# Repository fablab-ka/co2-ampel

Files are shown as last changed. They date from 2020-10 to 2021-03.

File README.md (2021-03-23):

# CO2-Ampel V2
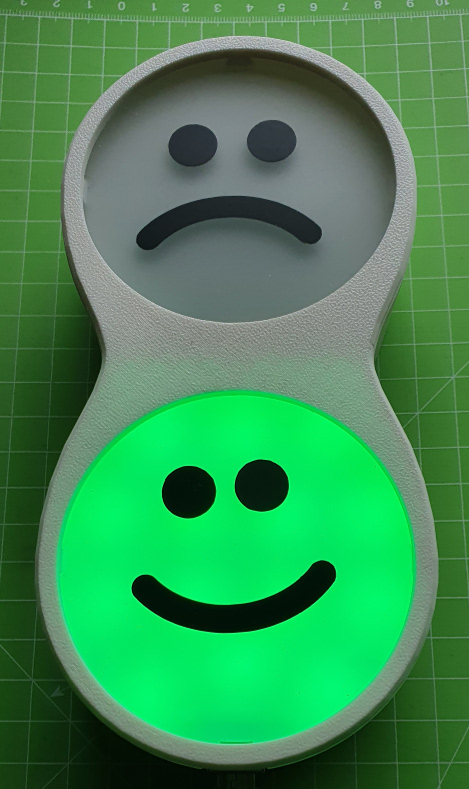
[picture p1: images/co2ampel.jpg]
CO2-Ampel


## Einleitung
Der CO2-Gehalt der Luft kann als Indikator benutzt werden, um das Raumklima zu überwachen und eine potentielle Virenlast in geschlossenen Räumen zu erkennen. In freier Natur und in frisch gelüfteten Räumen beträgt er ungefähr 400ppm (0,04%). In geschlossenen Räumen mit anwesenden Personen steigt er konstant an. Ab ca. 1500ppm wird das Raumklima schlecht, und es können Unbehaglichkeit, Müdigkeit und Konzentrationsschwächen auftreten. 

Da Viren, die als Aerosol übertragen werden, zusammen mit dem CO2 in den Raum gebracht werden, kann über den CO2-Gehalt der Raumluft als Indikator für das Ansteckungsrisiko dienen.

Mithilfe von CO2-Sensoren lässt sich der CO2-Gehalt der Raumluft überwachen. Viele vorhandenen Geräte erlauben zwar eine akkurate Messung, zeigen aber die Auswirkungen auf die Raumluft nur mit kleinen LED-Anzeigen oder überhaupt nicht an. Sie eignen sich daher nur bedingt für den Einsatz in Gruppenräumen.

## Zielsetzung
Die *CO2-Ampel V2* wurde speziell für Schulen und Kitas entwickelt. Sie zeigt das Raumklima spielerisch und gut sichtbar im Stil einer Verkehrsampel an. *Grün* bedeutet *alles in Ordnung*. Springt die Ampel auf *gelb*, wird es Zeit, die Fenster zu öffnen. Bei *rot* ist der Grenzwert überschritten. Ein akustisches Signal weist zusätzlich darauf hin, dass nunmehr umgehend gelüftet werden muss. Sobald der CO2-Gehalt sich normalisiert hat, springt die Ampel wieder auf *grün*. Ein lachender bzw. ein trauriger Smiley illustrieren das Messergebnis zusätzlich.

Das Gerät lässt sich leicht installieren und wird über ein gewöhnliches USB-Kabel mit Strom versorgt. Der eingebaute Sensor erlaubt präzise CO2-Messungen. Auf Wunsch lässt sich der Verlauf der Messwerte per WLAN in einem Web-Interface anzeigen und protokollieren.

Bei der CO2-Ampel V2 handelt es sich um ein gemeinsames Projekt des [FabLab Karlsruhe e.V.](https://fablab-karlsruhe.de) und des [FabLab Bruchsal e.V.](http://fablab-bruchsal.de) im Rahmen der Aktion [Corona-Hilfe Karlsruhe](https://coronahilfe-karlsruhe.de).

## Inbetriebnahme und Fehlerbehebung
Die [Bedienungsanleitung](Documentation/Deutsch/Bedienungsanleitung.md) der CO2-Ampel V2 erläutert alle erforderlichen Schritte zur Inbetriebnahme und zur Nutzung einer fertigen CO2-Ampel. Sie deckt die folgenden Aspekte ab:

* Installation und Stromversorgung
* Optische und akustische Signale
* Konfiguration der WLAN-Verbindung (optional)
* Zugriff auf die Messdaten und Protokolle (optional)
* Fehlerbehebung
* Technische Daten
* Entsorgung

## Aufbauanleitung (Bausatz)
Die bebilderte [Aufbauanleitung](Documentation/Deutsch/Aufbauanleitung.md) erklärt Schritt für Schritt, wie die CO2-Ampel aus den Einzelkomponenten zusammengesetzt wird. Dies umfasst die folgenden Schritte:

* Einstecken des Microcontrollers und des CO2-Sensors
* Einsetzen der Platine
* Zusammenstecken und Verschrauben des Geräts

## Beschaffung bzw. Herstellung der Komponenten
Die [Herstellungsanleitung](Documentation/Deutsch/Herstellungsanleitung.md) gibt einen Überblick, wie die Einzelkomponenten der CO2-Ampel basierend auf den Informationen in diesem GitHub-Repository hergestellt bzw. beschafft werden können. Die Anleitung umfasst die folgenden Abschnitte:

* Beschaffung der Bauteile
* Bestellung der Platine bei einem PCB-Haus
* Bestückung der Platine mit den SMD-Komponenten
* Einlöten der weiteren elektronischen Komponenten
* Kompilieren und Hochladen der Software
* Einrichtung des Webinterfaces für den Datenzugriff
* 3D-Druck des Gehäuses

In der bebilderten [Loetanleitung](Documentation/Deutsch/Loetanleitung) sind alle wichtigen Schritte zum Löten der Komponenten beschrieben. Wir haben uns hier auf das Einlöten der Through Hole Komponenten beschränkt.

## Weiterentwicklung des Projekts
Der gesamte Quellcode der CO2-Ampel V2 wurde in diesem  GitHub-Repository veröffentlicht. Er besteht aus den folgenden Komponenten:

* Platine ([Gerber](https://de.wikipedia.org/wiki/Gerber-Format))
* Software (c++)
* Gehäuse (Wahlweise [Autodesk Fusion 360](https://www.autodesk.de/products/fusion-360/overview) oder [OpenSCAD](https://www.openscad.org))

## Zusätzliche Ressourcen
  * https://wiki.fablab-karlsruhe.de/doku.php?id=projekte:2020:co2-ampel

[co2ampel]: images/co2ampel.jpg "CO2-Ampel"

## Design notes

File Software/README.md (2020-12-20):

# Arduino Sketch
## Voraussetzungen
In Klammern steht jeweils die von uns getestete Version.
- [Arduino IDE(1.8.13)][IDE]
- [Arduino core for ESP8266 WiFi chip (2.7.4)][esp8266core], siehe [Installationsanleitung von heise][esp8266heise]
- Arduino Libaries
  - [SparkFun SCD30 Arduino Library (1.0.8)][scd30lib]
  - [Adafruit BMP280 Library (2.1.0)][bmp280lib]
  - [Adafruit BME280 Library (2.1.1)][bme280lib]
  - [ArduinoJson (6.17.1)][arduinojsonlib] **HINWEIS**: Die [Version 6.17.0 hat einen Bug][arduinojsonbug] und ist daher aktuell nicht kompatibel. Bitte achtet darauf, die Version 6.17.1 oder 6.16.1 zu installieren.
  - [FastLED (3.3.3)][FstLED]
  - [PubSubClient (2.8.0)][pubsubclientlib]
  - [WiFiManager (2.0.3-alpha)][wifimanagerlib]

[IDE]: https://www.arduino.cc/en/software "aktuelle Arduino IDE(1.8.13)"
[esp8266core]: https://github.com/esp8266/Arduino "Arduino core for ESP8266 WiFi chip"
[esp8266heise]: https://www.heise.de/ct/artikel/Arduino-IDE-installieren-und-fit-machen-fuer-ESP8266-und-ESP32-4130814.html "Installationsanleitung von heise"
[scd30lib]: https://github.com/sparkfun/SparkFun_SCD30_Arduino_Library "SparkFun SCD30 Arduino Library (1.0.8)"
[bmp280lib]: https://github.com/adafruit/Adafruit_BMP280_Library "Adafruit BMP280 Library (2.1.0)"
[bme280lib]: https://github.com/adafruit/Adafruit_BME280_Library "Adafruit BMP280 Library (2.1.0)"
[arduinojsonlib]: https://github.com/bblanchon/ArduinoJson "ArduinoJson (6.16.1)"
[arduinojsonbug]: https://github.com/bblanchon/ArduinoJson/issues/1411 "Version 6.17.0 hat einen Bug"
[FstLED]: https://github.com/FastLED/FastLED "FastLED (3.3.3)"
[pubsubclientlib]: https://github.com/knolleary/pubsubclient/ "PubSubClient (2.8.0)"
[wifimanagerlib]: https://github.com/tzapu/WiFiManager "WiFiManager (2.0.3-alpha)"
[fsuploader]: https://github.com/earlephilhower/arduino-esp8266littlefs-plugin "Arduino ESP8266 LittleFS Filesystem Uploader"
## Installation
- Oben aufgeführte Libraries und Boards unter Arduino installieren
- LittleFS Uploader in <home_dir>/Arduino/tools entpacken
- Arduino Board auswählen: LOLIN(WEMOS) D1 R2 & mini

## Mikrocontroller flashen
- config.json im data Verzeichnis anpassen (MQTT Server, MQTT Zugangsdaten)
- Sketch compilieren und auf Board laden
- ESP8266 LittleFS Data Upload starten (kopiert die config.json und backup.json auf das Board). Der serielle Monitor muss dazu vorher geschlossen werden.

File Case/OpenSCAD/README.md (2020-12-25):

# OpenSCAD Case
Das Gehäuse ist nur für das PCBv2 geeignet. Das PCBv4.1 passt leider nicht. Das neuere Fusion360 v4 Gehäuse kann mit allen PCBs ab v2 verwendet werden.

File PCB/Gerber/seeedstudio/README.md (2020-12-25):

# Seedstudio PCB v2
Die Dateien beinhalten die veraltete PCB v2. Für neue Bestellungen empfehlen wir die PCB v4.1.

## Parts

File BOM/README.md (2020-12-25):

# BOM (Stückliste)

Alle Komponenten bzw. baugleiche Alternativen auch bei Digikey erhältlich. Die LEDs sind bei Digikey erheblich teurer. Der BMP280 ist nicht zwingend erforderlich, erhöht jedoch die Genauigkeit der CO2-Meßwerte.

Falls die WLAN Reichweite des D1 mini nicht ausreicht, kann alternativ der D1 mini pro mit externer Antenne eingesetzt werden. Meist muss dann der 0Ohm Widerstand auf dem D1-Board umgelötet werden. Mit den D1 mini von Aliexpress Händlern hatten wir trotz guter Bewertung teilweise sehr instabile WLAN Verbindungen.

| Nr  | MPN  | Anzahl  |Referenz |Wert|Hersteller|Footprint|LCSC-Nr|Digikey-Nr|
| --- | --- | --- | --- |--- |--- |--- |--- |--- |
|01|DMG2302UK-7|1|Q7|N-Mosfet|Diodes Incorporated|SOT-23-3|[C460977][C460977]||
|02|TCC0805X7R104M500DT|29|C2, C5-C8, C10-C33|100n| CCTC|0805_C|[C360619][C360619]||
|03|1206L110THYR|1|F1|Fuse 1A|Littelfuse|1206|[C126818][C126818] ||
|04|0805W8F4700T5E|2|R10, R12|470R|UNI-ROYAL|0805_R|[C17710][C17710]||
|05|VZH102M0JTR-0810|1|C1|1000u|Lelon|SMD,8x10mm |[C134811][C134811]||
|06|0805W8F4701T5E|3|R1, R3, R11|4.7k|UNI-ROYAL|0805_R|[C17673][C17673]|| 
|07a|BME280|1|IC1|BME280|Bosch Sensortec|LGA-8 |[C92489][C92489]||
|07b|BMP280|1|IC1|BMP280|Bosch Sensortec|LGA-8 |[C83291][C83291]||
|07c|12239814426720|1|JP1|[GY-BMP280][GY-BMP280]|AZ-Delivery|Through Hole|||
|08|SN74AHCT125DR|1|IC2|SN74AHCT125DR|Texas Instruments|SOIC-14_150mil|[C155176][C155176]||
|09|SS24|1|D1|Diode 2A| MDD(Microdiode Electronics)|SMB(DO-214AA)|[C35501][C35501]||
|10|WS2813C|28|LED1-LED28| WS2813C|Worldsemi|SMD,5x5mm |[C194323][C194323]||
|11|SK-12D02VG4|1|SW1|Switch|SOFNG SK-12D02VG4|Through Hole|[C239529][C239529]|[A107673-ND][A107673-ND]|
|12|C46392|1|J1|USB-B| Jing Extension of the Electronic Co.|Through Hole|[C46392][C46392]|[102-3999-ND][102-3999-ND]|
|13|YS-MBZ12085C05R42|1|SG1|Buzzer 5V|Fengming| 	Through Hole,12x8.5mm|[C409842][C409842]|[433-1028-ND][433-1028-ND]|
|14|SCD30|1|U$1|CO2-Sensor| Sensirion AG|Through Hole||[1649-1098-ND][1649-1098-ND]|
|15|MTF185-107SY1|1|SCD30 Header|7pin|MINTRON|Through Hole,P=2.54mm|[C358721][C358721]|[PPTC071LFBN-RC][PPTC071LFBN-RC]|
|16|28983931346|1|D1|[d1][d1] |AZDelivery|Through Hole|||
|17|[PCB-V4.1](../PCB/Gerber/jlcpcb)|1|PCB||jlcpcb||||
|18|[Case](../Case/Fusion360/Case.stl)|1|Gehäuse|PLA 0.2mm|3D-Druck||||
|19|[Lid](../Case/Fusion360/Lid.stl)|1|Deckel|PLA 0.2mm|3D-Druck||||
|20|Diffusor|2|Diffusor|[3mm Akryl opal 70% Lichtdurchlässigkeit](../Case/Laser/diffusor.svg) / [PETG transparent](../Case/Fusion360/glass_top.stl)|Lasercutter/3D-Druck||||
|21|[Smiley](../Case/SilhouetteStudio/smiley.svg)|1|Smiley|Vinyl Folie|Plotter/ausschneiden||||
|22|Netzteil|1|USB-Netzteil 5V/1A|Netzteil|diverse Hersteller||||
|23|USB-B-Kabel|1|USB-A Stekcer auf USB-B Buchse|USB-B-Kabel|diverse Hersteller||||

[C460977]: https://lcsc.com/product-detail/MOSFET_Diodes-Incorporated-DMG2302UK-7_C460977.html "C460977"
[C360619]: https://lcsc.com/product-detail/Multilayer-Ceramic-Capacitors-MLCC-SMD-SMT_CCTC-TCC0805X7R104M500DT_C360619.html "C360619"
[C126818]: https://lcsc.com/product-detail/PTC-Resettable-Fuses_Littelfuse-1206L110THYR_C126818.html "C126818"
[C17710]: https://lcsc.com/product-detail/Chip-Resistor-Surface-Mount_UNI-ROYAL-Uniroyal-Elec-0805W8F4700T5E_C17710.html "C17710"
[C134811]: https://lcsc.com/product-detail/Aluminum-Electrolytic-Capacitors-SMD_Lelon-VZH102M0JTR-0810_C134811.html "C134811"
[C17673]: https://lcsc.com/product-detail/Chip-Resistor-Surface-Mount_UNI-ROYAL-Uniroyal-Elec-0805W8F4701T5E_C17673.html "C17673"
[C92489]: https://lcsc.com/product-detail/Humidity-Sensors_Bosch-Sensortec-BME280_C92489.html "C92489"
[C83291]: https://lcsc.com/product-detail/Gas-Sensors_Bosch-Sensortec-BMP280_C83291.html "C83291"
[GY-BMP280]: https://www.az-delivery.de/en/collections/alle-produkte/products/azdelivery-bmp280-barometrischer-sensor-luftdruck-modul-fur-arduino-und-raspberry-pi "GY-BMP280"
[C155176]: https://lcsc.com/product-detail/Logic-Buffers-Drivers-Receivers-Transceivers_Texas-Instruments-SN74AHCT125DR_C155176.html "C155176"
[C35501]: https://lcsc.com/product-detail/Schottky-Barrier-Diodes-SBD_MDD-Microdiode-Electronics-SS24_C35501.html "C35501"
[C194323]: https://lcsc.com/product-detail/Light-Emitting-Diodes-LED_Worldsemi-WS2813C_C194323.html "C194323"
[C239529]: https://lcsc.com/product-detail/Lack-of-specifications_SOFNG-SK-12D02VG4_C239529.html "C239529"
[A107673-ND ]: https://www.digikey.de/product-detail/de/1825232-1/A107673-ND/4021554/?itemSeq=347804695 "A107673-ND "
[C46392]: https://lcsc.com/product-detail/USB-Connectors_Jing-Extension-of-the-Electronic-Co-C46392_C46392.html "C46392"
[102-3999-ND]: https://www.digikey.de/product-detail/de/UJ2-BH-1-TH/102-3999-ND/6187914/?itemSeq=347804690 "102-3999-ND"
[C409842]: https://lcsc.com/product-detail/Buzzers_Fengming-YS-MBZ12085C05R42_C409842.html "C409842"
[433-1028-ND]: https://www.digikey.de/product-detail/de/WT-1205/433-1028-ND/479674/?itemSeq=347804693 "433-1028-ND"
[1649-1098-ND]: https://www.digikey.de/product-detail/de/sensirion-ag/SCD30/1649-1098-ND/8445334 "1649-1098-ND"
[C358721]: https://lcsc.com/product-detail/Pin-Header-Female-Header_MINTRON-MTF185-107SY1_C358721.html "C358721"
[PPTC071LFBN-RC]: https://www.digikey.de/product-detail/de/sullins-connector-solutions/PPTC071LFBN-RC/S7005-ND/810146 "PPTC071LFBN-RC"
[d1]: https://www.az-delivery.de/products/d1-mini?variant=28983931346 "D1 Mini NodeMcu mit ESP8266-12F"

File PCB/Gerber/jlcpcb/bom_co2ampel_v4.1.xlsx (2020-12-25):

Comment | Designator | Footprint | LCSC Part #（optional）
DMG2302UK-7 | Q7 | SOT-23-3 | C460977
100n | C2, C5, C6, C7, C8, C10, C11, C12, C13, C14, C15, C16, C17, C18, C19, C20, C21, C22, C23, C24, C25, C26, C27, C28, C29, C30, C31, C32, C33 | C-EUC0805 | C49678
1206L110THYR | F1 | R-EU_R1206 | C126818
470R | R10, R12 | R-EU_R0805 | C17710
VZH102M0JTR-0810 | C1 | SMD,8x10mm | C134811
4.7k | R1, R3, R11 | R-EU_R0805 | C17673
BME280 | IC1 | LGA-8 | C92489
SN74AHCT125 | IC2 | SOIC-14_150mil | C155176
SS24 | D1 | SMB(DO-214AA) | C35501
WS2813C | LED1, LED2, LED3, LED4, LED5, LED6, LED7, LED8, LED9, LED10, LED11, LED12, LED13, LED14, LED15, LED16, LED17, LED18, LED19, LED20, LED21, LED22, LED23, LED24, LED25, LED26, LED27, LED28 | SMD,5x5mm | C194323

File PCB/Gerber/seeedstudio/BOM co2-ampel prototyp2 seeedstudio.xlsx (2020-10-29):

Designator | MPN | Qty | Link
VR1 | AZ1117EH-2.5TRG1 | 1 | https://www.digikey.de/product-detail/de/diodes-incorporated/AZ1117EH-2-5TRG1/AZ1117EH-2-5TRG1DICT-ND/5001337
Q1, Q2, Q3, Q4, Q7 | DMG2302UK-7 | 5 | https://www.digikey.de/product-detail/de/diodes-incorporated/DMG2302UK-7/DMG2302UK-7DICT-ND/6010163
C2, C5, C6, C7, C8, C9, C10, C11, C12, C13, C14, C15, C16, C17, C18, C19, C20, C21, C22, C23, C24, C25, C26, C27, C28, C29, C30, C31, C32, C33 | CC0805KRX7R9BB104 | 30 | https://www.digikey.de/product-detail/de/yageo/CC0805KRX7R9BB104/311-1140-2-ND/302874
R1, R2, R3, R4, R6, R7, R8, R9, R11 | RC0805FR-0710KL | 9 | https://www.digikey.de/product-detail/de/yageo/RC0805FR-0710KL/311-10-0KCRTR-ND/727535
C3, C4 | CC1206KKX5R8BB106 | 2 | https://www.digikey.de/product-detail/de/yageo/CC1206KKX5R8BB106/311-1466-1-ND/2833772
F1 | 0468003.NRHF | 1 | https://www.digikey.de/product-detail/de/littelfuse-inc/0468003-NRHF/F5706CT-ND/3306963
R10, R12 | RC0805JR-071KL | 2 | https://www.digikey.de/product-detail/de/yageo/RC0805JR-071KL/311-1-0KARCT-ND/731165
C1 | HV102M6R3F105ETR | 1
IC2 | BMP280 | 1 | https://www.digikey.de/product-detail/de/bosch-sensortec/BMP280/828-1064-1-ND/6136315
D1 | SS24T3G | 1 | https://www.digikey.de/product-detail/de/on-semiconductor/SS24T3G/SS24T3GOSCT-ND/964638
LED1, LED2, LED3, LED4, LED5, LED6, LED7, LED8, LED9, LED10, LED11, LED12, LED13, LED14, LED15, LED16, LED17, LED18, LED19, LED20, LED21, LED22, LED23, LED24, LED25, LED26, LED27, LED28 | WS2813C | 28

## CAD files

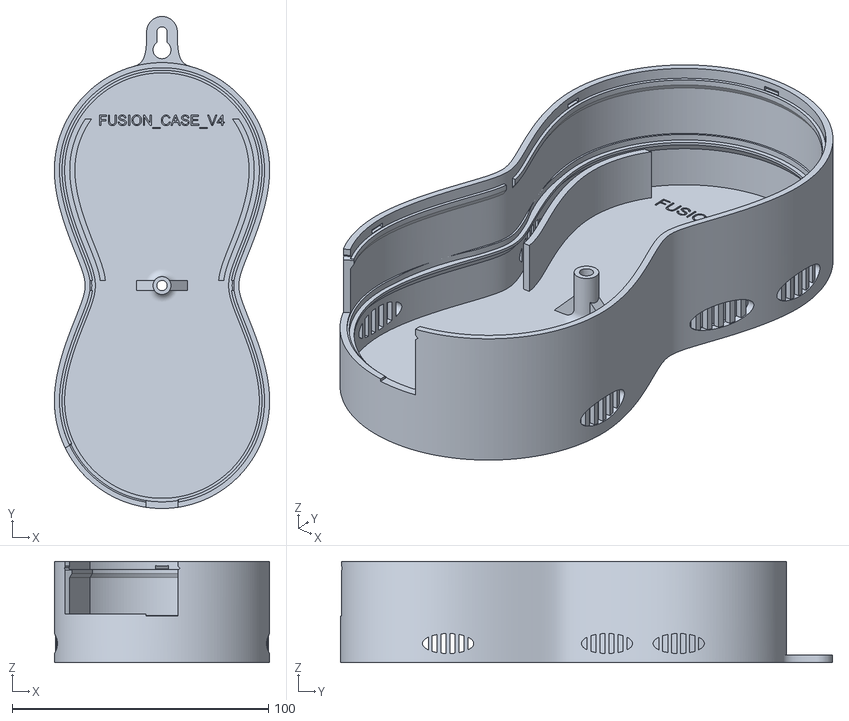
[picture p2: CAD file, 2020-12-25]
Case/Fusion360/Case.stl
84.0 x 192.0 x 39.6

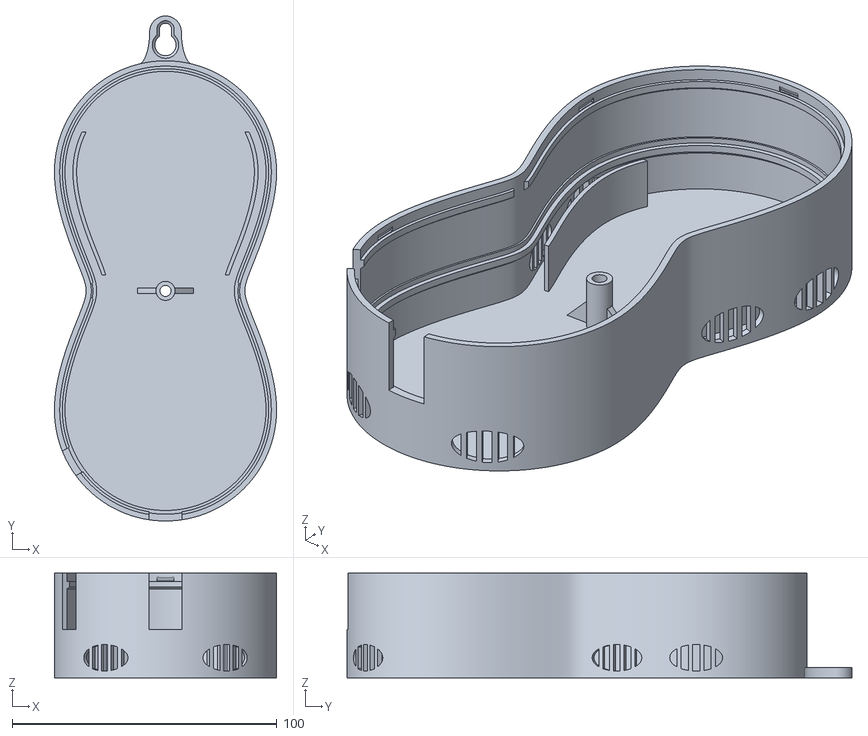
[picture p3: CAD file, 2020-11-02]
Case/OpenSCAD/PCBv2/case.stl
84.0 x 190.9 x 39.6

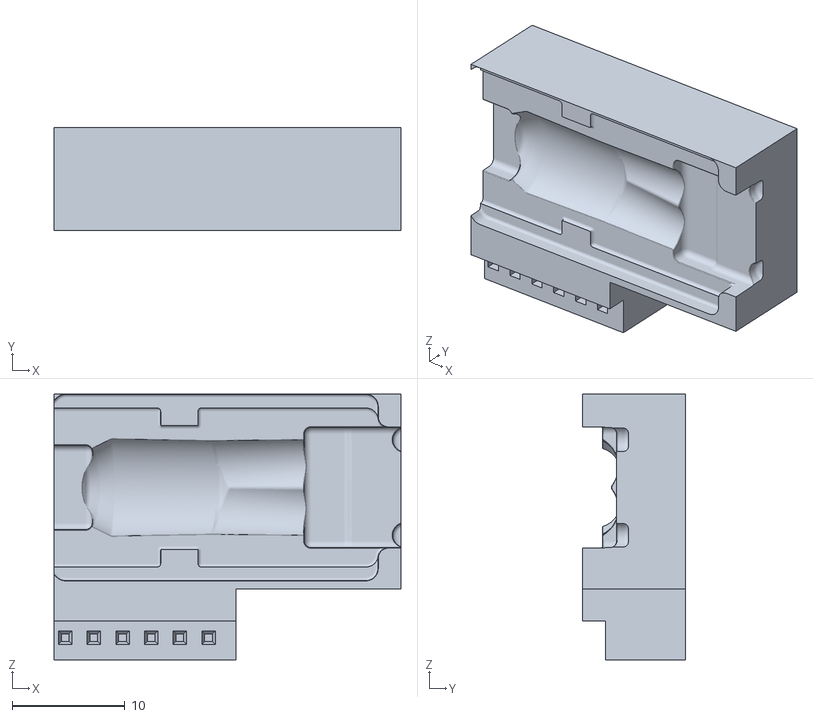
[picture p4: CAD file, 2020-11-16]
PCB/scd30-bestuecken.stl
30.7 x 9.08 x 23.5

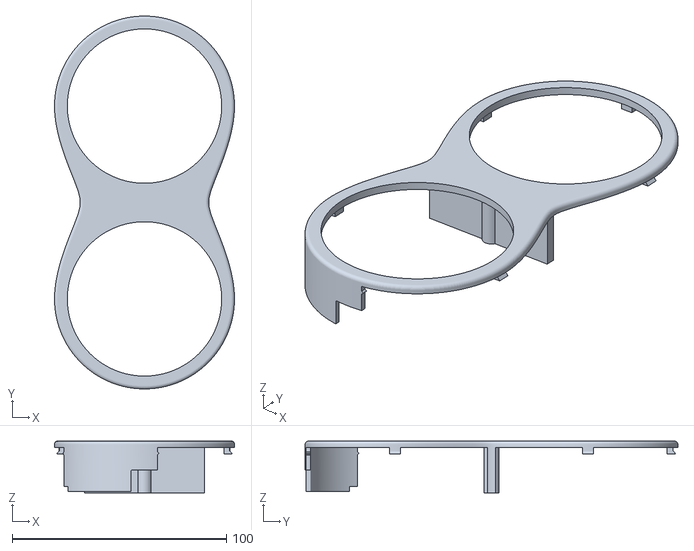
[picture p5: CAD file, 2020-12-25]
Case/Fusion360/Lid.stl
84.0 x 174.0 x 24.2

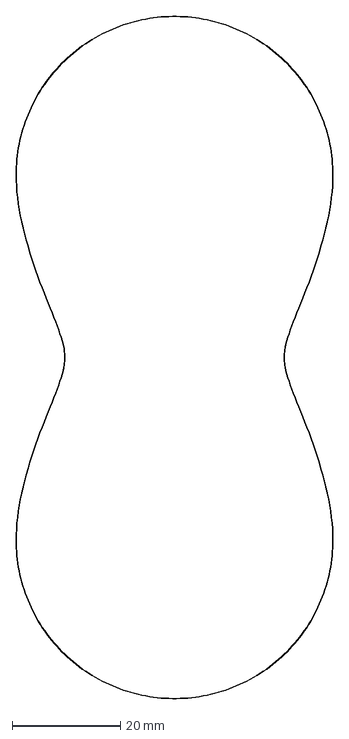
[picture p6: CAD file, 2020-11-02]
Case/OpenSCAD/PCBv2/pcb_v2.dxf
58.5 x 126.0 mm

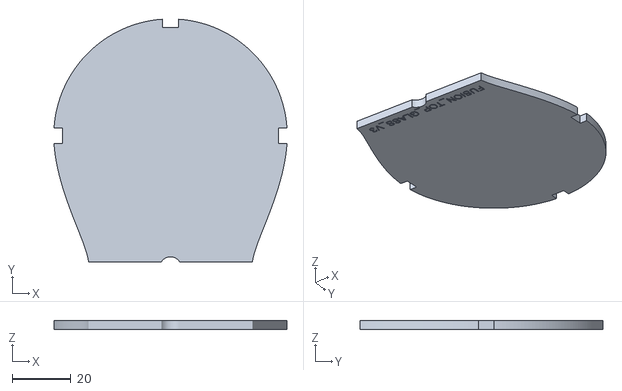
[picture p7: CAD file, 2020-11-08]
Case/Fusion360/glass_top.stl
79.4 x 82.7 x 3.00

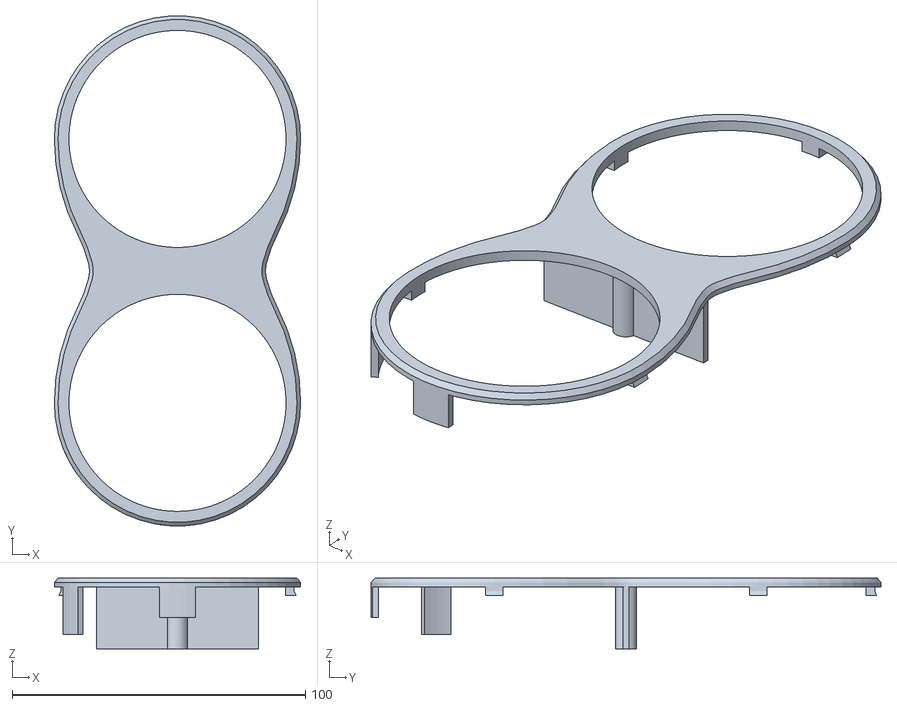
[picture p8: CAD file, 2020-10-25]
Case/OpenSCAD/PCBv2/lid.stl
84.0 x 173.9 x 24.2

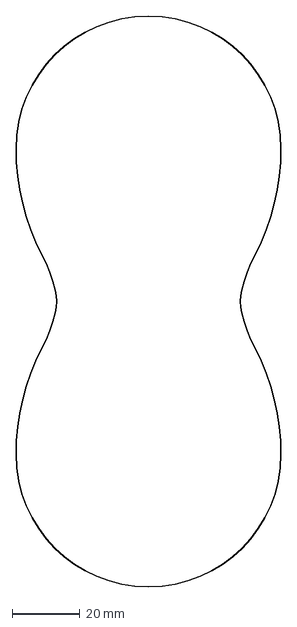
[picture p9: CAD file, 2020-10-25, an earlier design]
Case/OpenSCAD/PCBv2/pcb.dxf
78.0 x 168.0 mm

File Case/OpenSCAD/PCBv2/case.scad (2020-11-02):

use </mnt/io/gemeinsam/prusa/Bevel_Extrude_Module_for_OpenSCAD/bevel_extrude.scad>

$fn=100;
pcb_length=168;
pcb_width=78;


wall=2; //min=2 !
base=1.6;
gap=1;

enclosure();

module enclosure(){
    difference(){
        union(){
            difference(){
                union(){
                    translate([-39,-84,0]) linear_extrude(height=base+38, center = false, convexity = 200) offset(r=wall+gap) import (file = "pcb_v2.dxf");
                    translate([0,88.9+wall,2]) wallFastening();
                }
                translate([-39,-84,0]) translate([0,0,base]) linear_extrude(height=38, center = false, convexity = 200) offset(r=gap)  import (file = "pcb_v2.dxf");
                //translate([0,0,0.5*base]) cylinder(d1 = 10.2, d2 = 4.2, h = base, center = true);
                //translate([0,0,1]) cylinder(d1 = 10.2, d2 = 4.2, h = 2, center = true);
                translate([0,0,0.5*base]) cylinder(d1 = 10.8, d2 = 4.2, h = base, center = true);
        
                airConditioning();
                //antennaHole();
            }
            screwFastening();
            pcbBearing();
            difference(){
                lidBearing();
                translate([25,0,base+33]) cylinder(d = 8, h = 5, center = true);
                translate([-25,0,base+33]) cylinder(d = 8, h = 5, center = true);
            }
            blowProtection();
        }
        powerHole();
        switchHole();
        lidFastening();
    }
}


module pcb(){
color("green")  linear_extrude(height = 1.6, center = false, convexity = 200)
   import (file = "pcb_v2.dxf");       
}


module antennaHole(){
    r = 39.8;
    alpha = 120;

    translate([0,45,base+6]) translate([r*cos(alpha),r*sin(alpha),0]) rotate([0,0,alpha])
    rotate([0,90,0]) cylinder(d=6.4, h=10, center = true);
}


module lidFastening(){
    r = 39.8;
    
    //top segment
    translate([0,45,base+35]){
        alpha = 90;
        translate([r*cos(alpha),r*sin(alpha),0]) rotate([0,0,alpha]) lidHole();
    
        beta = 0;
        translate([r*cos(beta),r*sin(beta),0]) rotate([0,0,beta]) lidHole();
    
        gamma = 180;
        translate([r*cos(gamma),r*sin(gamma),0]) rotate([0,0,gamma]) lidHole();
    }
    
    //base segment
    translate([0,-45,base+35]){
        beta = 0;
        translate([r*cos(beta),r*sin(beta),0]) rotate([0,0,beta]) lidHole();
    
        gamma = 180;
        translate([r*cos(gamma),r*sin(gamma),0]) rotate([0,0,gamma]) lidHole();
    }
}


module lidHole(){
    rotate([90,0,0]) linear_extrude(height = 6.5, center = true) polygon(points = [[0,0], [0.8,0], [0,1.6]]);
}


module wallFastening(){
    difference(){
        union(){
            cube([21,14,4], center = true);
            translate([0,7,0]) cylinder(d=12, h=4, center = true);
        }
        translate([10.5,7,0]) scale([1,2.75,1]) cylinder(d=9, h=4, center =true);
        translate([-10.5,7,0]) scale([1,2.75,1]) cylinder(d=9, h=4, center =true);
        translate([0,2,0]) cylinder(d = 8, h = 4, center = true);
        translate([0,8,0]) cylinder(d = 4.5, h = 4, center = true);
        translate([0,4,0]) cube([4.5,8,4], center = true); 
        
        translate([0,0,4]) mirror([0,0,1]) bevel_extrude(height=4, bevel_depth=2, $fn=50)
        union(){
            translate([0,2,0]) circle(d=10);
            translate([0,4,0]) square([6.5, 8], center = true);
            translate([0,8,0]) circle(d=6.5);
        }
    }
}


module switchHole(){
    alpha = -151;
    translate([45*cos(alpha),45*sin(alpha)-45,base+28.6]) rotate([0,0,alpha]) cube([15,10.6,24], center = true);
}


module powerHole(){
    translate([0,-85,base+28.6]) cube([12.4,10,24], center = true);
}


module airConditioning(){
    //top segment
    translate([42,45,base+6]) airHole(4);    //right side
    translate([35,15,base+6]) rotate([0,0,-20]) airHole(4);  //right side

    translate([-42,45,base+6]) airHole(4);   //left side
    translate([-35,15,base+6]) rotate([0,0,20]) airHole(4);  //left side
    
    //translate([42,45,base+24]) airHole(4);    //right side
    //translate([-42,45,base+24]) airHole(4);   //left side
    
    //base segment
    alpha = 30; //bottom = -90°
    translate([45*cos(-90+alpha),45*sin(-90+alpha)-40,base+6]) rotate([0,0,-90+alpha]) airHole(4);
    translate([45*cos(-90-alpha),45*sin(-90-alpha)-40,base+6]) rotate([0,0,-90-alpha]) airHole(4);
    
    //translate([45*cos(-90+alpha),45*sin(-90+alpha)-40,base+24]) rotate([0,0,-90+alpha]) airHole(4);
    //translate([45*cos(-90-alpha),45*sin(-90-alpha)-40,base+24]) rotate([0,0,-90-alpha]) airHole(4);
}


module airHole(n){
    l=20;
    d=1.6;
    a = (l-n*d)/(n+1);
    difference(){
        scale([1,2,1]) rotate([0,90,0]) cylinder(d = 0.5*l, h = 10, center = true);
        for (i = [0:1:n]){
            translate([0,((0.5+i)*d+(i+1)*a)-10,0]) cube([15,d,15], center = true);
        }
    }
}


module blowProtection(){
    difference(){
         translate([-39,-84,base]) linear_extrude(height = 14.5, center = false, convexity = 200) offset(r=-4)  import (file = "pcb_v2.dxf");
        translate([-39,-84,base]) linear_extrude(height = 14.5, center = false, convexity = 200) offset(r=-5.4)  import (file = "pcb_v2.dxf");
        translate([0,-44,base+7.25]) cube([100,100,14.5], center = true);
        translate([0,85,base+7.25]) cube([100,50,14.5], center = true);
    }
}


module lidBearing(){
    translate([-39,-84,0]) translate([0,0,base+34.8]) mirror([0,0,1]) bevel_extrude(height=10, bevel_depth=8, $fn=50) lidBearingSkew();
    
}


module lidBearingSkew(){
    difference(){
        offset(r=gap+1.6)  import (file = "pcb_v2.dxf");
        offset(r=gap-1)  import (file = "pcb_v2.dxf");
    }
}


module pcbBearing(){
    difference(){
        translate([-39,-84,0]) translate([0,0,base+15]) linear_extrude(height = 1.6, center = false, convexity = 200) offset(r=gap)  import (file = "pcb_v2.dxf");
        //translate([-39,-84,0]) translate([0,0,base+15]) linear_extrude(height = 1.6, center = false, convexity = 200) offset(r=gap-0.8)  import (file = "pcb_v2.dxf");
        translate([-39,-84,0]) translate([0,0,base+15]) linear_extrude(height = 1.6, center = false, convexity = 200) offset(r=gap-0.6)  import (file = "pcb_v2.dxf");
    }

    translate([-39,-84,0]) translate([0,0,base+15]) mirror([0,0,1]) bevel_extrude(height=10, bevel_depth=8, $fn=50) pcbBearingSkew();
}


module pcbBearingSkew(){
    difference(){
        offset(r=gap+1.6) import (file = "pcb_v2.dxf");
        offset(r=gap-2) import (file = "pcb_v2.dxf");
    }
}


module screwFastening(){
    translate([0,0,base]){
        difference(){
            union(){
                cylinder(d = 7.2, h = 15);
                rotate([0,45,0]) cube([15,2,15], center = true);
            }
            translate([0,0,-6]) cube([20,4,12], center = true);
            translate([0,0,-base]) cylinder(d = 4.2, h = base + 18.1);
        }
    }
}

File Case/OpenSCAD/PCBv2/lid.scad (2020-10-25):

// CO2 Ampel - Case
// By: FabLab Karlsruhe e.V., Martina Feger
// Date: 19.10.2020
// License: MIT

// https://www.thingiverse.com/thing:135408/files
use <Bevel_Extrude_Module_for_OpenSCAD/bevel_extrude.scad>

$fn=100;
pcb_length=168;
pcb_width=78;

wall=2; //min=2 !
base=2;
lidThick=3;
gap=1;  //puffer (auf jeder seite) zwischen pcb und gehaeuse

lid();

module lid(){
    difference(){
        union(){
            mirror([0,0,1]) translate([-39,-84,lidThick]) mirror([0,0,1]) bevel_extrude(height=lidThick, bevel_depth=(0.5*lidThick), $fn=50) offset(r=wall+gap) import (file = "/mnt/io/gemeinsam/co2ampel/pcb.dxf");
            screwFastening();
            lidFastening();
        }
        translate([0,45,-10]) cylinder(d=74, h=20, center = false); //top window
        translate([0,-45,-10]) cylinder(d=74, h=20, center = false); //bottom window
    }
    powerHoleFilling();
    switchHoleFilling();
}


module lidFastening(){
    lidHoleFilling(0,"top");
    lidHoleFilling(90,"top");
    lidHoleFilling(180,"top");
    
    lidHoleFilling(0,"bottom");
    lidHoleFilling(180,"bottom");
}


module lidHoleFilling(alpha, segment){
    r = 39.8;
    if (segment == "top"){
        intersection(){
            translate([-39,-84,-(8+lidThick)]) linear_extrude(height=8, center = false, convexity = 200) offset(r=1) import (file = "/mnt/io/gemeinsam/co2ampel/pcb.dxf");
            translate([0,45,-(lidThick+1.5)]) translate([r*cos(alpha),r*sin(alpha),0]) rotate([0,0,alpha]) translate([-4,0,0]) cube([8,6,3], center = true);
        }
        translate([0,45,-(lidThick+3)]) translate([r*cos(alpha),r*sin(alpha),0]) rotate([0,0,alpha]) rotate([90,0,0]) linear_extrude(height = 6, center = true) polygon(points = [[0,0], [0.7,0], [0,1.5]]);
    } else if (segment == "bottom"){
        intersection(){
            translate([-39,-84,-(8+lidThick)]) linear_extrude(height=8, center = false, convexity = 200) offset(r=1) import (file = "/mnt/io/gemeinsam/co2ampel/pcb.dxf");
            translate([0,-45,-(lidThick+1.5)]) translate([r*cos(alpha),r*sin(alpha),0]) rotate([0,0,alpha]) translate([-4,0,0]) cube([8,6,3], center = true);
        }
        translate([0,-45,-(lidThick+3)]) translate([r*cos(alpha),r*sin(alpha),0]) rotate([0,0,alpha]) rotate([90,0,0]) linear_extrude(height = 6, center = true) polygon(points = [[0,0], [0.7,0], [0,1.5]]);
    }
}



module powerHoleFilling(){
    translate([0,0,-10.4]) intersection(){
        difference(){
            translate([-39,-84,-lidThick]) linear_extrude(height=10.4, center = false, convexity = 200) offset(r=wall+gap) import (file = "/mnt/io/gemeinsam/co2ampel/pcb.dxf");
            translate([-39,-84,-lidThick]) linear_extrude(height=10.4, center = false, convexity = 200) offset(r=gap)  import (file = "/mnt/io/gemeinsam/co2ampel/pcb.dxf");
        }
        //translate([0,-85,0]) cube([12.4,10,24], center = true);
        translate([0,-85,0]) cube([12.2,10,24], center = true);
    }
}


module switchHoleFilling(){
    translate([0,0,-16.2]) intersection(){
        difference(){
            translate([-39,-84,-lidThick]) linear_extrude(height=16.2, center = false, convexity = 200) offset(r=wall+gap) import (file = "/mnt/io/gemeinsam/co2ampel/pcb.dxf");
            translate([-39,-84,-lidThick]) linear_extrude(height=16.2, center = false, convexity = 200) offset(r=gap)  import (file = "/mnt/io/gemeinsam/co2ampel/pcb.dxf");
        }
        alpha = -151;
        //translate([45*cos(alpha),45*sin(alpha)-45,13]) rotate([0,0,alpha]) cube([15,10.6,34], center = true);
        translate([45*cos(alpha),45*sin(alpha)-45,13]) rotate([0,0,alpha]) cube([15,10.4,34], center = true);
    }
}


module screwFastening(){
    translate([0,0,-(21.2+lidThick)]){
        difference(){
            union(){
                cylinder(d = 7.2, h = 21.2, centre = true);
                translate([0,0,10.6]) cube([55.4,2,21.2], center = true);
            }
            cylinder(d = 3.2, h = 21.2, center = true);
        }
    }
}

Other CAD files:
Case/Fusion360/glass_bottom.stl

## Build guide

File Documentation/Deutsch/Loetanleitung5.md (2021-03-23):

# CO2-Ampel Lötanleitung - PCB v4.1

## Teil V - Platine prüfen
### Benötigte Bauteile
1. Platine aus Schritt IV

### Benötigtes Werkzeug
* Multimeter

In diesem Teil messen wir mit einem Multimeter, ob es eine Kurzschluss zwischen plus und minus bzw. zwischen den Datenleitungen vorhanden ist. Die könnten beim ersten Einschalten dazu führen, dass die Bauteile oder die Platine beschädigt wird.

### Arbeitsschritte
1. Stellt eurer Multimeter entweder auf Durchgangsprüfer oder auf den niedrigsten Widerstandswert ein. Wenn ihr jetzt testweise die Messspitzen aneinander haltet, piept es entweder, oder es wird ein sehr kleiner Widerstand (ca. 0.1 Ohm) angezeigt.
2. An der BMP280 Platine sind fast alle zu messenden Leitungen vorhanden. Haltet die Messspitzen als erstes an VCC und GND. Wenn das Multimeter piepst oder einen kleinen Widerstand anzeigt, habt ihr einen Kurzschluss und müsst nochmals alle Lötstellen prüfen. Wiederholt die Messung mit folgenden Pins:
  * 3V3 + SCL
  * 3V3 + SDA
  * GND + SCL
  * GND + SDA
  * SCL + SDA

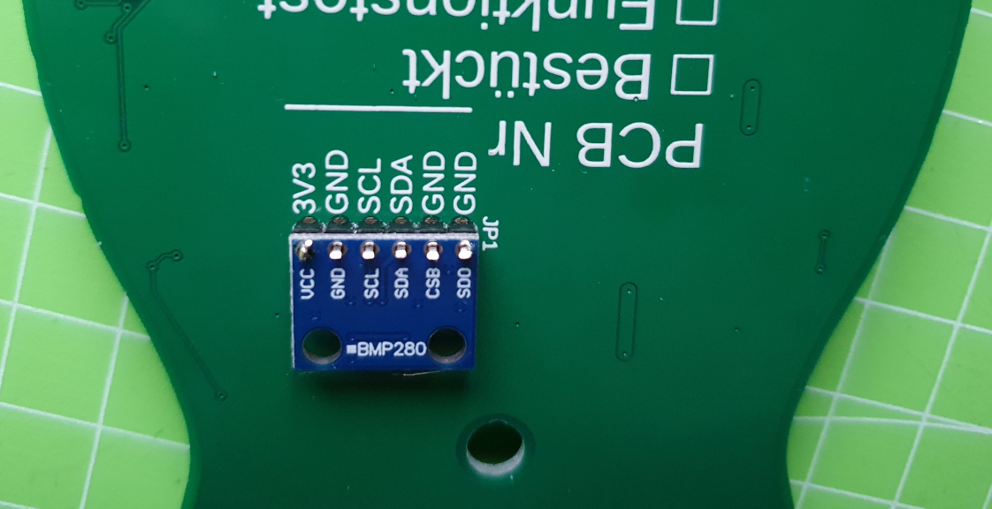
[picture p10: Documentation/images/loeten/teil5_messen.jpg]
Bauteile und Werkzeug Teil V


3. Als letztes messen wir noch den Widerstand zwischen 5V und Masse (GND). Das geht am besten an den beiden linken unteren PINs des Mikrocontrollers (siehe Bild) 

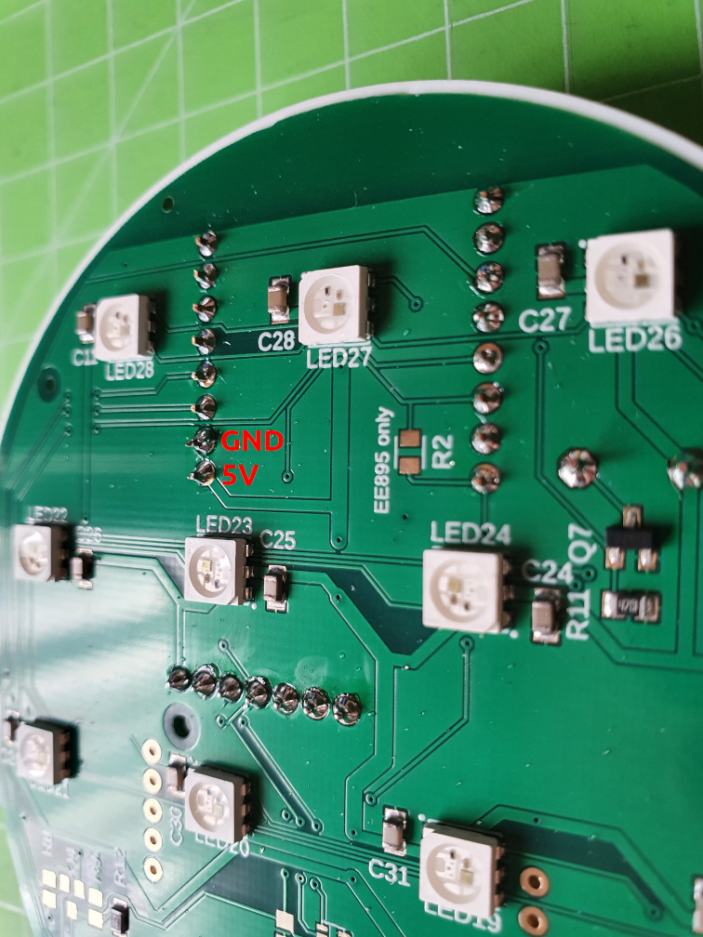
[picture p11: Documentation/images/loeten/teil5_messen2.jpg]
Bauteile und Werkzeug Teil V


**Die Ampel darf erst an den Strom angeschlossen werden, wenn alle Kurzschlüsse beseitigt sind**

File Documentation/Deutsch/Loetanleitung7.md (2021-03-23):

# CO2-Ampel Lötanleitung - PCB v4.1

## Teil VII - Test der Ampel

### Benötigte Bauteile
1. geprüfte Platine aus Schritt VI
2. USB-Netzteil
3. USB-Kabel (A-Stecker auf B-Stecker)

Bauteile und Werkzeug Teil VII

### Arbeitsschritte
1. Schutzaufkleber auf dem Buzzer entfernen
2. CO2-Ampel mit dem Kabel an das Netzteil anschließen
3. Selbsttest abwarten. Wenn alles richtig gemacht wurde, leuchten zuerst alle LEDs kurz weiß und blinken dann grün. 
4. CO2-Sensor leicht anpusten. Er sollte nach ein paar Sekunden auf gelb/rot springen und der Buzzer sollte zu hören sein. 
5. Wenn der Selbsttest erfolgreich war und auch der Buzzer funktioniert, könnt ihr die Ampel [fertig zusammen bauen](Aufbauanleitung.md) und dann direkt einsetzen.

Wir hoffen es hat alles geklappt und ihr hattet Spaß beim Löten. Wenn es Probleme gibt oder ihr unsicher seid, dann meldet euch gerne bei uns.

### Eure FabLabs Karlsruhe & Bruchsal

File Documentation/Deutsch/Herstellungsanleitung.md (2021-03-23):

# Herstellungsanleitung CO2-Ampel V2

> Hinweis: Dieses Dokument ist in Arbeit

## Benötigtes Werkzeug

* 3D Drucker
* Lötkolben
* optional: Reflow Ofen (falls das PCB selbst bestückt werden soll)
* optional: Lasercutter (falls der Diffusor aus Acryl gelasert statt gedruckt werden soll)
* optional: Plotter für die Vinyl-Folie (Augen, Mund)

## Komponenten

* 1 Gehäuse mit Deckel
* 2 Scheiben
* Aufkleber für die beiden Smileys
* Platine mit bereits eingelöteten SMD-Komponenten
* CO2-Sensor
* 1 Buchsenleiste, Polzahl 7 
* 1 Stiftleiste, Polzahl 7
* Lötleisten für CO2-Sensor (Länge 7)
* 1 ESP8266 (WeMos D1 mini V2)
* 2 Buchsenleisten, Polzahl 8 
* 2 Stiftleisten, Polzahl 8
* Schalter
* USB-Buchse
* Schraube
* Typenschild

## Einlöten der elektronischen Komponenten

* Setzt eine gewisse Erfahrung im Umgang mit Lötapparaten voraus
* Nur Elektronik-Lötapparat mit feiner Spitze
* Bleifreies Lötzinn empfohlen

In der bebilderten [Loetanleitung](Documentation/Deutsch/Loetanleitung) sind alle wichtigen Schritte zum Löten der Komponenten beschrieben. Wir haben uns hier auf das Einlöten der Through Hole Komponenten beschränkt.

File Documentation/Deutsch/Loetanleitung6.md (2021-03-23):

# CO2-Ampel Lötanleitung - PCB v4.1

## Teil VI - CO2-Sensor

### Benötigte Bauteile
1. geprüfte Platine aus Schritt V
2. Stiftleiste 7pin
3. scd30 CO2-Sensor

### Benötigtes Werkzeug
* 3D-gedruckte Löthilfe für den scd30
* Lötstation (temperaturgeregelt)
* Lötrauchabsaugung
* Lötzinn (bleifrei 0.5-0.75mm Durchmesser)
* Erdungsarmband

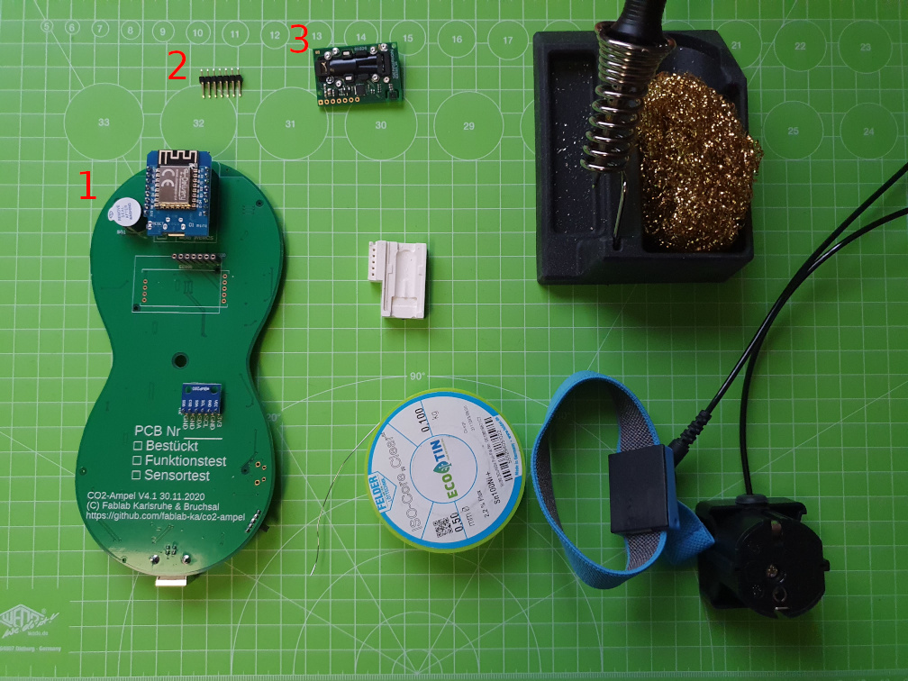
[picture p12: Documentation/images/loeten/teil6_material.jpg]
Bauteile und Werkzeug Teil VI


### Arbeitsschritte
Der Sensor ist das teuerste Bauteil und sehr empfindlich. Wenn ihr hier zu lange an einer Stelle lötet oder mit der heißen Lötspitze eines der SMD-Bauteile auf der Platine  berührt, könnt ihr ihn irreparabel beschädigen.

Der Sensor ist außerdem empfindlich gegen elektrostatische Aufladung. Ihr solltet daher bei diesem Schritt ein **Erdungsarmband tragen** und ihn nur am Rand anfassen.

1. Stiftleiste in die Löthilfe stecken (kurze Beine schauen raus)

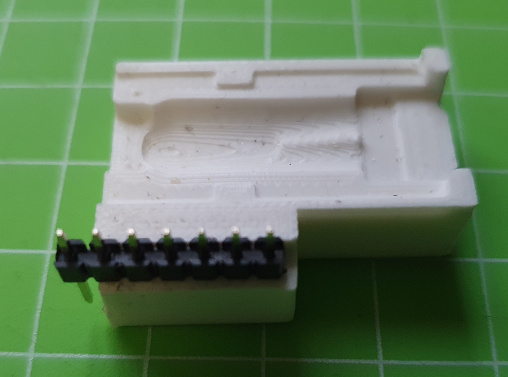
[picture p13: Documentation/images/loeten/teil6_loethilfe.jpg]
scd30 loethilfe 1


2. Sensor einlegen (es gibt nur eine Position die passt). Vorsichtig andrücken.

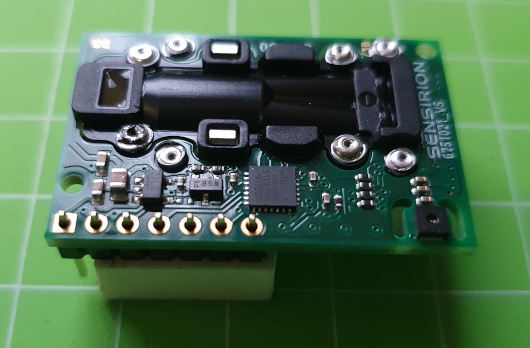
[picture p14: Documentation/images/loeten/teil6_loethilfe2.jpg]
scd30 loethilfe 2


3. Pins vorsichtig löten
4. **Qualitätskontrolle:** Auch nach diesem Schritt bitte nochmal alle Lötstellen wie oben beschrieben prüfen. 
5. Sensor auf die Platine stecken. Hier müsst ihr unbedingt darauf achten, dass der Sensor richtig sitzt und alle Pins in der Buchse stecken. **Wenn ihr ihn nur um einen Pin versetzt einsteckt, wird er beim Einschalten sofort zerstört.**

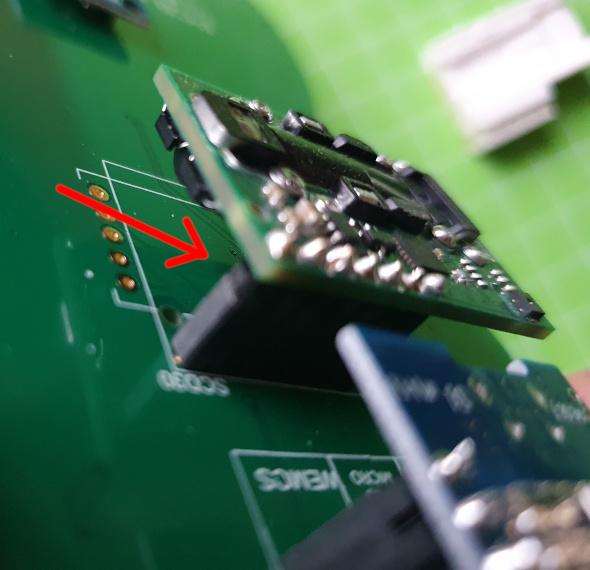
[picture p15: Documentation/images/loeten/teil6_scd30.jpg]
scd30 richtig auf die Platine stecken


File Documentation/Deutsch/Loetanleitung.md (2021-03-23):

# CO2-Ampel Lötanleitung - PCB v4.1

## Vorbereitung
Den D1 Mikrocontroller könnt ihr schon vorab mit dem Arduino Programm flashen. Dann könnt ihr direkt nach dem Löten die Ampel testen.

Prüft bitte bevor ihr beginnt, ob ihr alle benötigten Teile und Werkzeuge habt:

## Benötige Bauteile
* Buchse 8pin (2x): Diese findet ihr beim D1 Mikrocontroller
* Buchse 7pin (1x)
* bmp280 Platine
* Stiftleiste 6pin (1x): Diese findet ihr bei der bmp280 Platine
* Stiftleiste 8pin (2x): Diese findet ihr beim D1 Mikrocontroller
* D1 Mikrocontroller
* Buzzer (1x)
* SMD bestückte Platine
* USB-Buchse
* Schalter
* scd30 CO2-Sensor
* Stiftleiste 7pin
* USB-Netzteil
* USB-Kabel (A-Stecker auf B-Stecker)

## Benötigtes Werkzeug
* 3D-gedruckte Löthilfe für die Platine
* 3D-gedruckte Löthilfe für den scd30
* Lötstation (temperaturgeregelt)
* Lötrauchabsaugung
* Lötzinn (bleifrei 0.5-0.75mm Durchmesser)
* Seitenscheider
* Schutzbrille
* Multimeter
* Erdungsarmband
* evtl. eine Entlötpumpe, falls doch mal ein Bauteil falsch eingelötet wurde

Die Lötanleitung besteht aus 7 Teilen (inkl. Test der Ampel):

* [Teil I: Stiftleisten, Sockel und Buzzer](Loetanleitung1.md)
* [Teil II: USB-Buchse und Schalter](Loetanleitung2.md)
* [Teil III: bmp280 Zusatzplatine](Loetanleitung3.md)
* [Teil IV: D1 Mikrocontroller](Loetanleitung4.md)
* [Teil V - Platine prüfen](Loetanleitung5.md)
* [Teil VI - CO2-Sensor](Loetanleitung6.md)
* [Teil VII - Test der Ampel](Loetanleitung7.md)

Wir wünschen euch viel Spaß beim Löten.
Eure FabLabs Karlsruhe & Bruchsal

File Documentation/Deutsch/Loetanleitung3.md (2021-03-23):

# CO2-Ampel Lötanleitung - PCB v4.1

## Teil III: bmp280 Zusatzplatine

### Benötigte Bauteile
1. Platine aus Teil II
2. bmp280 Platine

### Benötigtes Werkzeug
* 3D-gedruckte Löthilfe für die Platine
* Lötstation (temperaturgeregelt)
* Lötrauchabsaugung
* Lötzinn (bleifrei 0.5-0.75mm Durchmesser)
* Seitenschneider

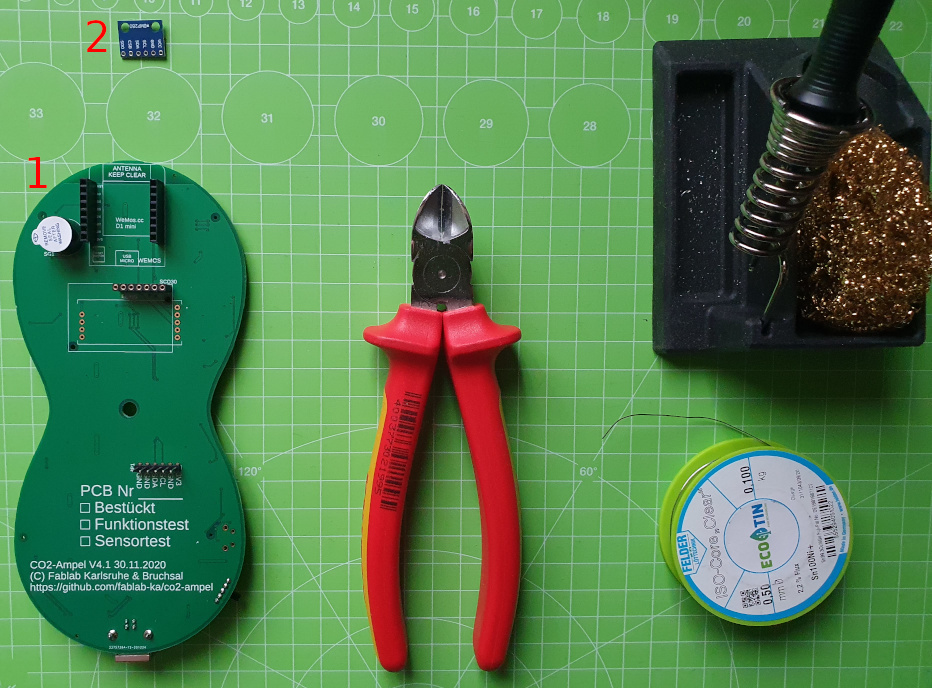
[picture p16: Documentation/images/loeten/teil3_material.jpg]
Bauteile und Werkzeug Teil III


### Arbeitsschritte
1. Legt die kleine Platine so wie auf dem Bild zu sehen, auf die Stiftleiste. **WICHTIG:** Prüft hier nochmals, ob sie richtig herum platziert wurde (**3.3V = VCC**).

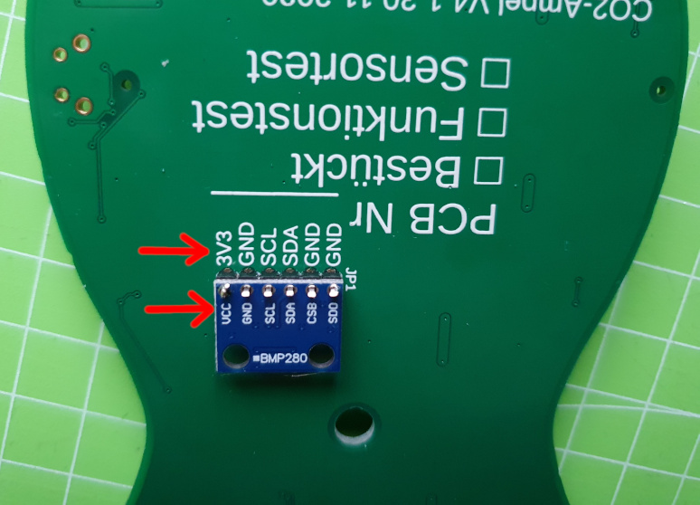
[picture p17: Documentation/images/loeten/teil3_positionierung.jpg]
bmp280 Positionierung


2. Haltet die kleine Platine waagerecht und lötet den ersten Pin. Wenn das Lötzinn kalt ist, könnt ihr die Platine los lassen und nochmal prüfen, ob sie waagerecht sitzt.
3. Lötet die restlichen Pins
4. **Qualitätskontrolle:** Auch nach diesem Schritt bitte nochmal alle Lötstellen wie oben beschrieben prüfen.

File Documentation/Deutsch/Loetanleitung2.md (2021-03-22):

# CO2-Ampel Lötanleitung - PCB v4.1

## Teil II: USB-Buchse und Schalter

### Benötigte Bauteile
1. Platine aus Teil I
2. USB-Buchse
3. Schalter

### Benötigtes Werkzeug
* 3D-gedruckte Löthilfe für die Platine
* Lötstation (temperaturgeregelt)
* Lötrauchabsaugung
* Lötzinn (bleifrei 0.5-0.75mm Durchmesser)

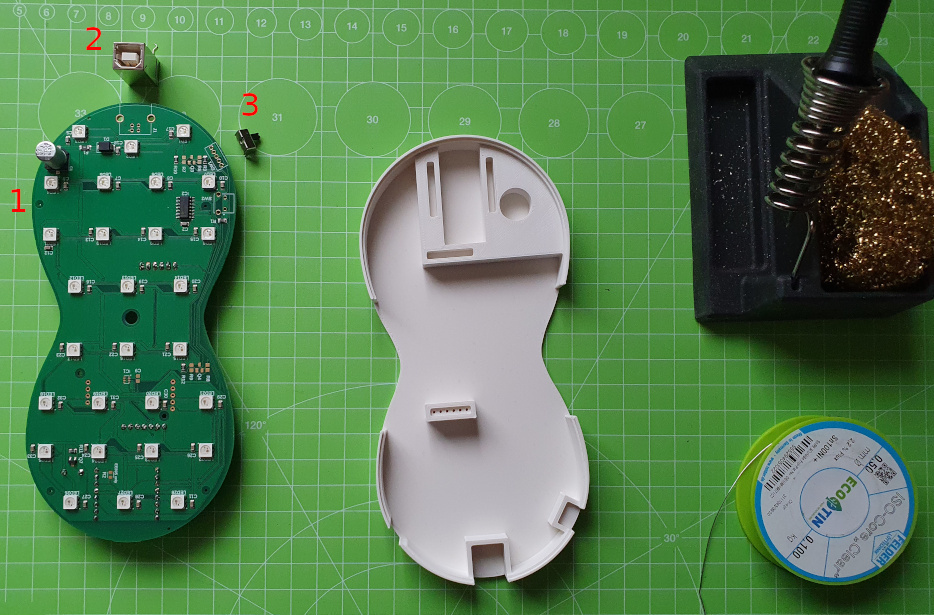
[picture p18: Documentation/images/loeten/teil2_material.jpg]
Bauteile und Werkzeug Teil II


### Arbeitsschritte
Auf der Platine sind die Positionen der Bauteile weiß markiert. Achtet bitte vor allem in diesem Teil darauf, dass ihr die Bauteile auf der richten Seite auf die Platine steckt.
1. USB-Buchse auf die Platine stecken (auf der Seite **mit** den LEDs)
2. Schalter auf die Platine stecken (auf der Seite **mit** den LEDs)

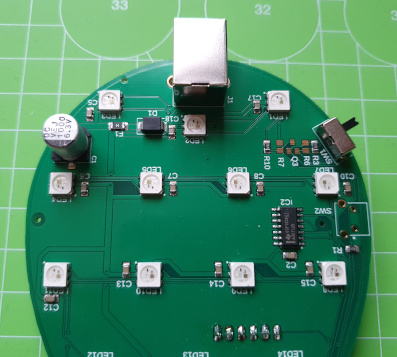
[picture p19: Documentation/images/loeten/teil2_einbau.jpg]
USB-Buchse und Schalter eingesetzt


3. Platine in Löthilfe einlegen und wieder fest andrücken, so dass die Ränder bündig sind
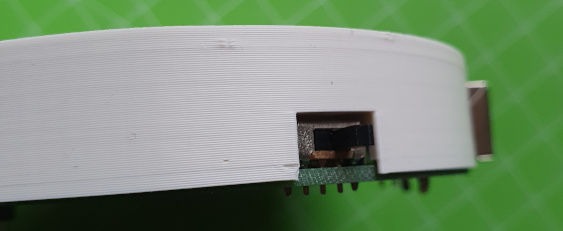
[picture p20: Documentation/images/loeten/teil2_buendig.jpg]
Platine buendig in Löthilfe

4. USB-Buchse Befestigung (a) anlöten: Hier braucht ihr viel Lötzinn. Am schnellsten geht es, wenn ihr hier 1-2mm dickes Lötzinn verwendet. Falls ihr nur dünnes habt, dann am besten etwas Zinn auf der flachen Seite der Lötspitze sammeln und erst dann die Lötspitze an die Lötstelle halten. Hier ist es ok, wenn ihr die Lötspitze 4-5 Sekunden an die Lötstelle haltet. Bitte aber nicht länger, denn sonst erhitzt sich die Abschirmung zu stark und das Plastik schmilzt. Die Buchse nochmal auszulöten macht keinen Spaß.
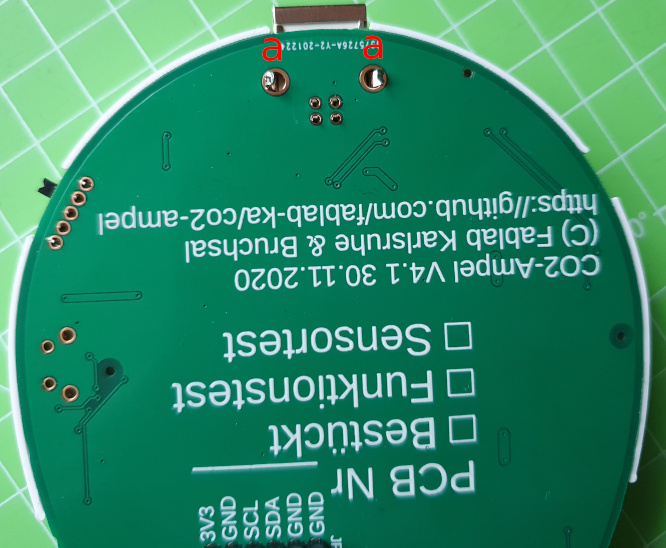
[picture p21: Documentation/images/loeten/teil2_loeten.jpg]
USB-Buchse und Schalter löten

5. Jetzt könnt ihr die restlichen Pins anlöten. Die 4 Pins der USB Buchse sitzen recht eng beeinander. Dreht euch am besten die Platine immer so, dass ihr bequem von außen die Lötspitze ansetzen könnt.
6. **Qualitätskontrolle:** Auch nach diesem Schritt bitte nochmal alle Lötstellen wie oben beschrieben prüfen. 
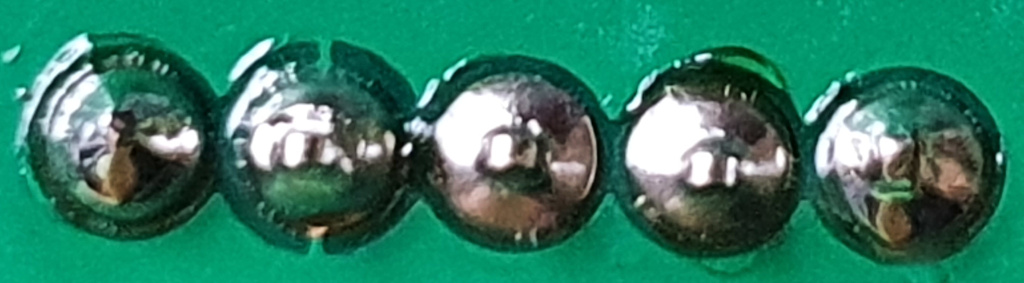
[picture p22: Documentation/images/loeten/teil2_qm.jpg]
USB-Buchse und Schalter QM


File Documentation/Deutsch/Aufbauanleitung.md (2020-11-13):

# Aufbauanleitung CO2 Ampel V2 (Bausatz)

Der Zusammenbau des Bausatzes der CO2-Ampel erfordert lediglich einige wenige Handgriffe, die in dieser Anleitung beschrieben sind.

## Kurzanleitung

Der Bausatz sich in wenigen Schritten zusammensetzen, die weiter unten im Detail beschrieben sind:

1. CO2-Sensor und Microcontroller (ESP) wie auf der Platine vorgezeichnet in diese einstecken ([Antistatikband](https://de.wikipedia.org/wiki/Antistatikband) verwenden!)
2. Platine so in das Gehäuse einlegen, dass Microcontroller und CO2-Sensor nach unten zeigen.
3. Die beiden Ampelscheiben in den Deckel des Gehäuses einsetzen: Trauriges Gesicht Richtung Aufhänger, fröhliches Gesicht Richtung USB-Buchse.
4. Den Deckel mit samt der Scheiben auf das Gehäuse stecken bis er einrastet.
5. Das Gehäuse an der Unterseite mit der beigefügten Schraube sichern.
6. Die Ampel wie in der [Bedienungsanleitung](Bedienungsanleitung.md) beschrieben in Betrieb nehmen.

## Übersicht der Komponenten

Bitte prüfen Sie vor dem Zusammenbau die Vollständigkeit der Einzelteile:

* Platine mit bereits eingelöteten Bauteilen und Buchsenleisten
* CO2-Sensor ([SCD30](https://www.digikey.de/product-detail/de/sensirion-ag/SCD30/1649-1098-ND/8445334)) mit eingelöteter Steckerleiste
* Microcontroller ([D1 Mini NodeMcu](https://www.az-delivery.de/products/d1-mini?variant=28983931346)) mit eingelöteten Steckerleisten
* Zwei Ampelscheiben mit aufgeklebten Gesichtern
* Unterteil des Gehäuses mit Typenschild
* Deckel des Gehäuses
* Schraube

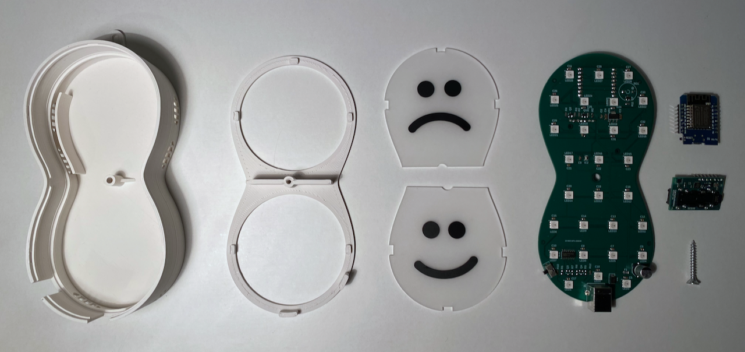
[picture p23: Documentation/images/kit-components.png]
Komponenten des Bausatzes


## Einstecken der elektronischen Komponenten

ACHTUNG: Bitte handhaben Sie die elektronischen Komponenten vorsichtig und vermeiden Sie elektrostatische Aufladungen! Wir empfehlen die Verwendung eines [Antistatikbandes](https://de.wikipedia.org/wiki/Antistatikband). Falls keines zur Verfügung steht, erden Sie sich während der Montage durch Berühren der eines Wasserhahns, eines Heizkörpers oder des Erdungsbügels einer Steckdose. Vermeiden Sie außerdem das Berühren der Metallteile des CO2-Sensors!

Entnehmen Sie den Microcontroller aus dem Antistatik-Beutel und stecken Sie ihn mit der WLAN-Antenne nach außen wie auf der Platine vorgezeichnet in diese ein. Wiederholen Sie den Schritt nun mit dem CO2-Sensor und achten Sie dabei besonders auf elektrostatische Aufladungen.

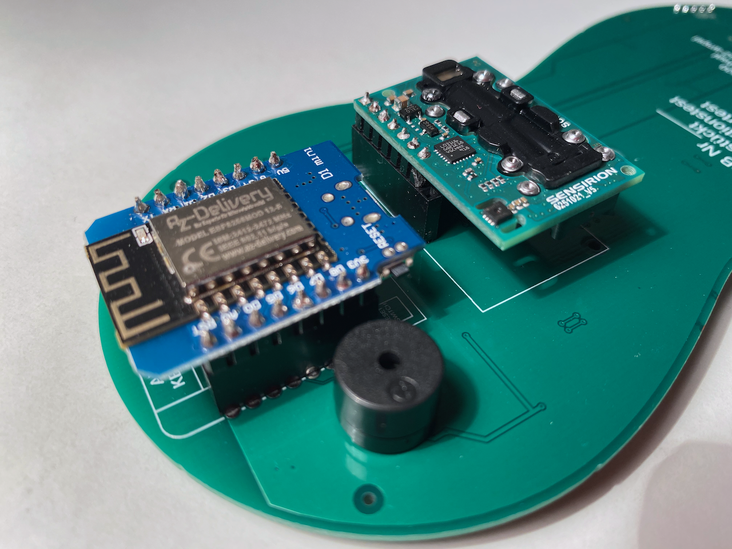
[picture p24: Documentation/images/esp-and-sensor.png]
Microcontroller und CO2-Sensor auf Platine


## Einsetzen der Platine

ACHTUNG: Berühren Sie beim Einbau der Platine nicht die elektronischen Komponenten sondern fassen Sie die Platine nur am Rand oder an der USB-Buchse an.

Setzen Sie die Platine nun so in das Unterteil des Gehäuses ein, dass der Microcontroller und der CO2-Sensor sich auf der Unterseite befinden und die USB-Buchse sich in die dafür vorgesehene Aussparung des Gehäuses einfügt.

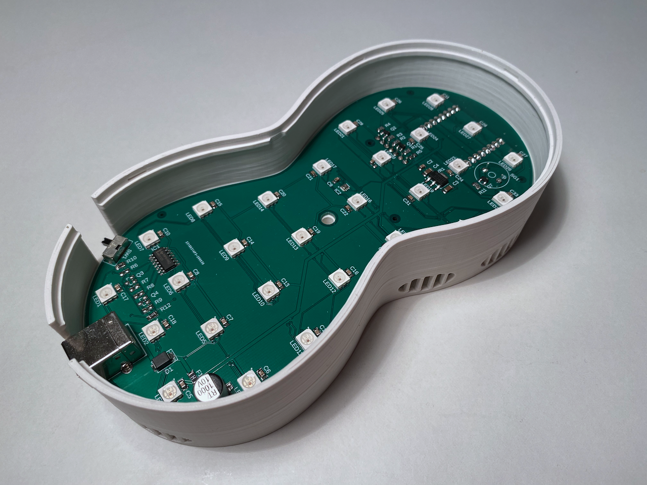
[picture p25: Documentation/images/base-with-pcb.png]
Platine im Unterteil des Gehäuses


## Zusammenstecken und Verschrauben des Gehäuses

Das Gehäuse kann nun in wenigen Schritten zusammengesteckt werden:

### 1. Einsetzen der Scheiben

Zunächst werden die beiden Ampelscheiben so in den Deckel eingesetzt, dass die aufgeklebten Gesichter nach unten zeigen. Sie werden sich später also an der Außenseite des Geräts befinden. Auf dem Foto sind sie daher nur verschwommen zu erkennen. Das fröhliche Gesicht zeigt in Richtung der beiden hervorstehenden Zungen, die sich später am unteren Rand des Geräts befinden werden. Das traurige Gesicht wird sich am oberen Rand des Geräts befinden. Jede Scheibe verfügt über drei Aussparungen an denen Sie von am Deckel angebrachten Nasen gehalten wird.

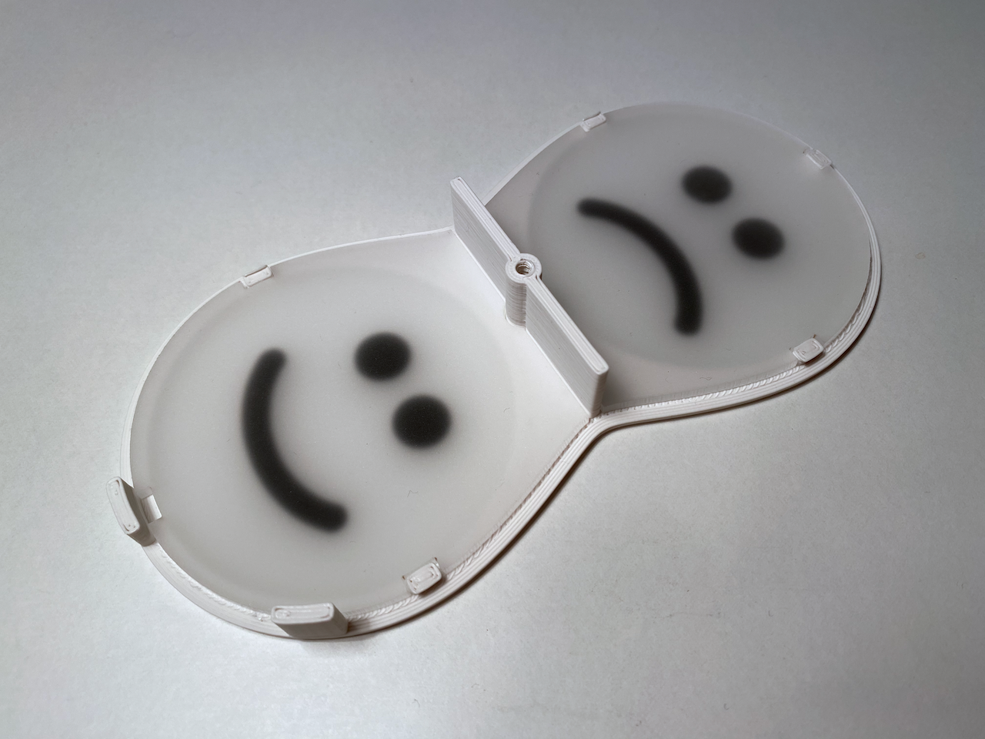
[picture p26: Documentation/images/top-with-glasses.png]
Deckel des Gehäuses mit eingesetzten Scheiben


### 2. Anbringen des Deckels

Nun werden Unterteil und Deckel gekippt, so dass weder die Platine noch die Scheiben herausfallen. Dann wird das Gehäuse zusammengedrückt, bis der Deckel in das Unterteil einrastet.

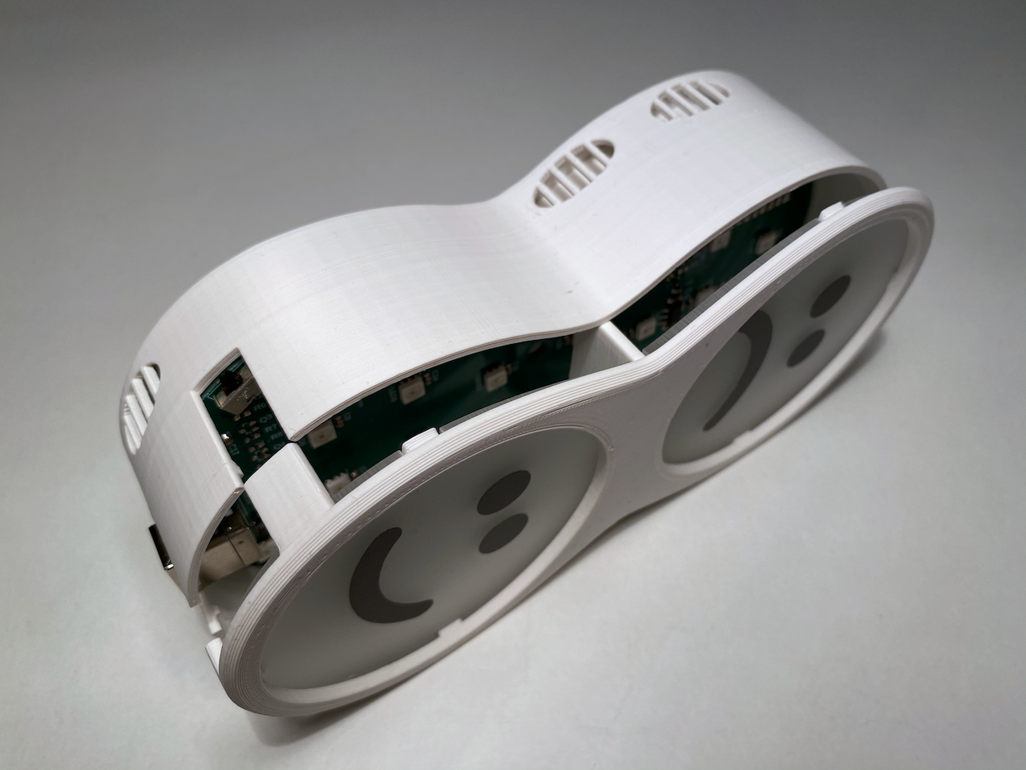
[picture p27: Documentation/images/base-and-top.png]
Anbringen des Deckels


### 3. Verschrauben des Gehäuses

Schließlich werden Unterteil und Deckel von der Unterseite des Gehäuses mit der beigefügten Schraube gesichert. Dafür ist ein Kreuzschlitzschraubendreher erforderlich. Das Typenschild ist auf dem Foto nicht abgebildet.

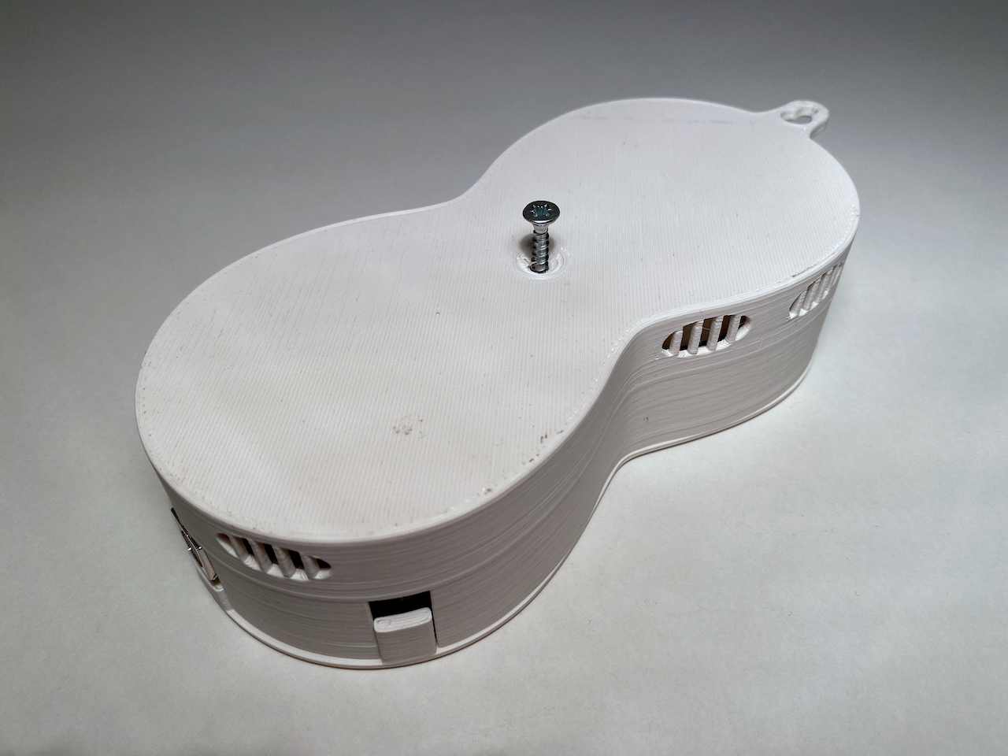
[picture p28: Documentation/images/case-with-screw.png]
Verschrauben des Gehäuses


## Inbetriebnahme

Die fertige CO2-Ampel V2 kann nun in Betrieb genommen werden. Folgen Sie dazu bitte der separaten [Bedienungsanleitung](Bedienungsanleitung.md).

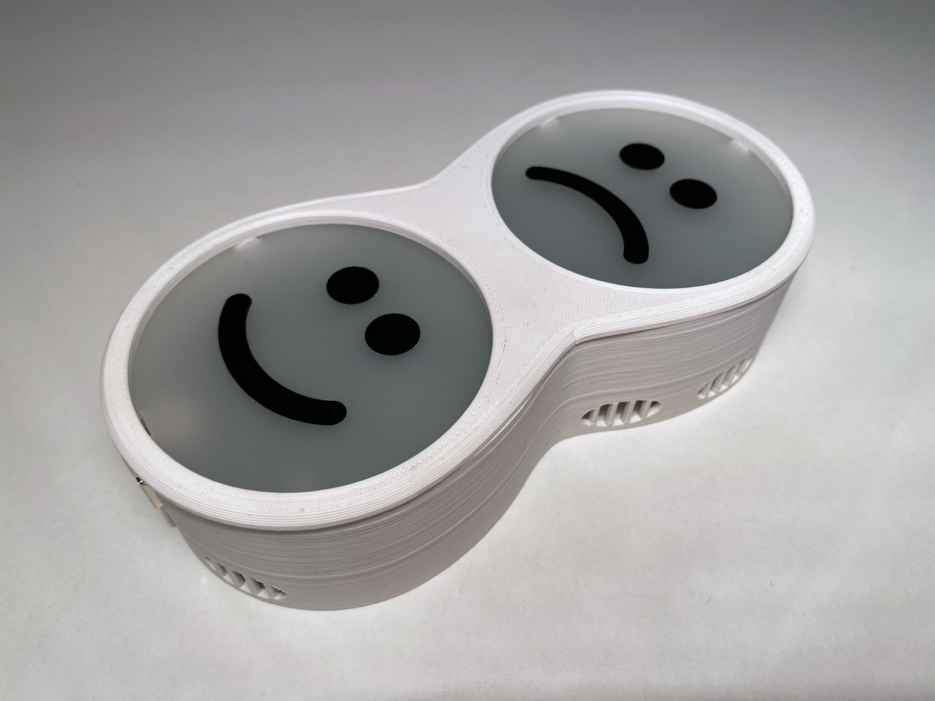
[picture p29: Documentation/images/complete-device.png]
Fertig zusammengesetzte CO2-Ampel V2


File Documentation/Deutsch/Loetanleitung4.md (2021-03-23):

# CO2-Ampel Lötanleitung - PCB v4.1

## Teil IV: D1 Mikrocontroller

### Benötigte Bauteile
1. Platine aus Teil III
2. 8pin Stiftleisten (2x): Diese findet ihr beim D1 Mikrocontroller
3. D1 Mikrocontroller

### Benötigtes Werkzeug
* Lötstation (temperaturgeregelt)
* Lötrauchabsaugung
* Lötzinn (bleifrei 0.5-0.75mm Durchmesser)

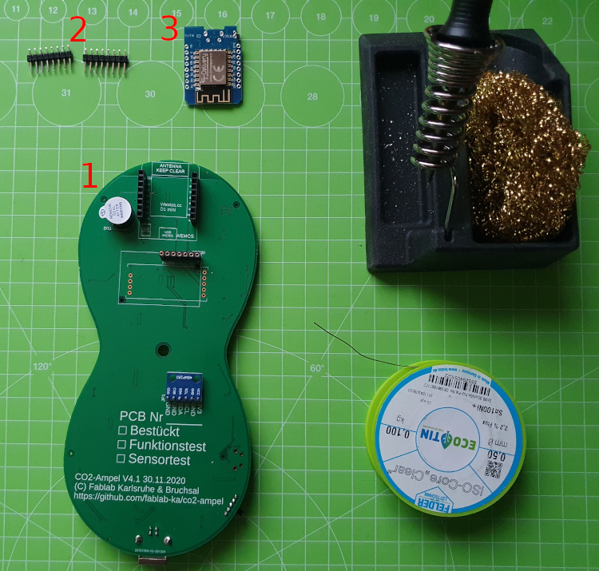
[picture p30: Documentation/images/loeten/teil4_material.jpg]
Bauteile und Werkzeug Teil IV


### Arbeitsschritte
1. Steckt die beiden 8pin Stiftleisten in die Buchsen (a+b). **WICHTIG:** Die kurzen Enden schauen nach oben raus.

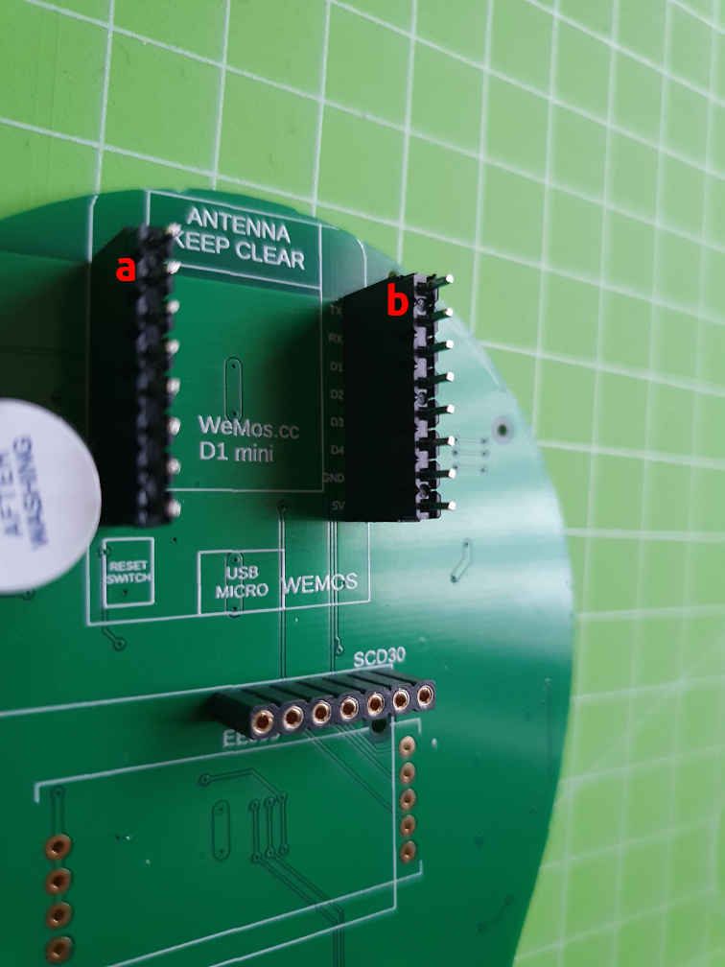
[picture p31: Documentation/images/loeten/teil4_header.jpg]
Teil IV - Header einsetzen


2. Legt den Mikrocontroller ein und achtet darauf, dass er richtig herum platziert ist. Die Antenne muss nach außen und die Mikro-USB Buchse des Controllers nach innen schauen. Auf der Platine ist dies auch in weiß eingezeichnet.

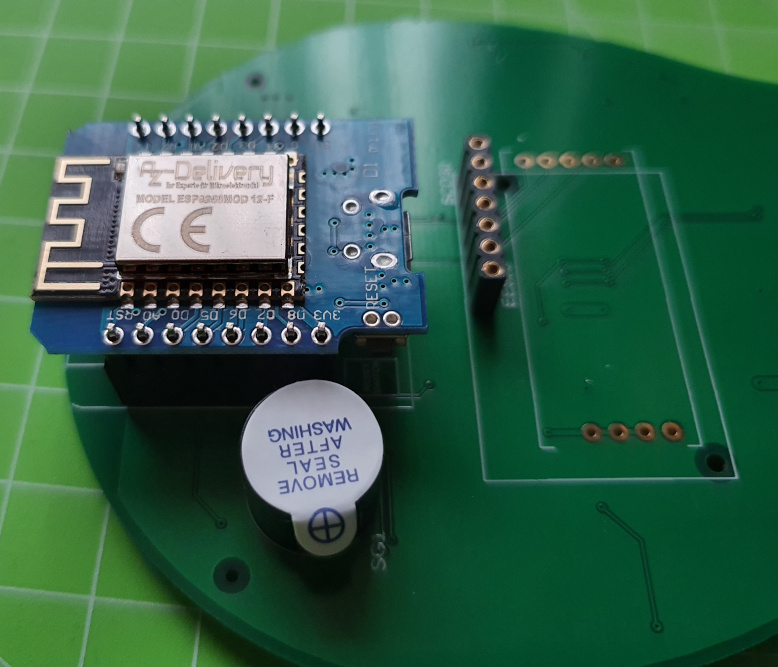
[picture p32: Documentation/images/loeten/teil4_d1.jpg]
Teil IV - D1


3. Drückt den Mikrocontroller auf die Stiftleiste und lötet zunächst die 4 äußeren Pins (a,b,c,d). Auch hier ist es wieder wichtig, dass ihr die Lötspitze von außen zum Mikrocontroller führt und das Lötzinn von Innen.

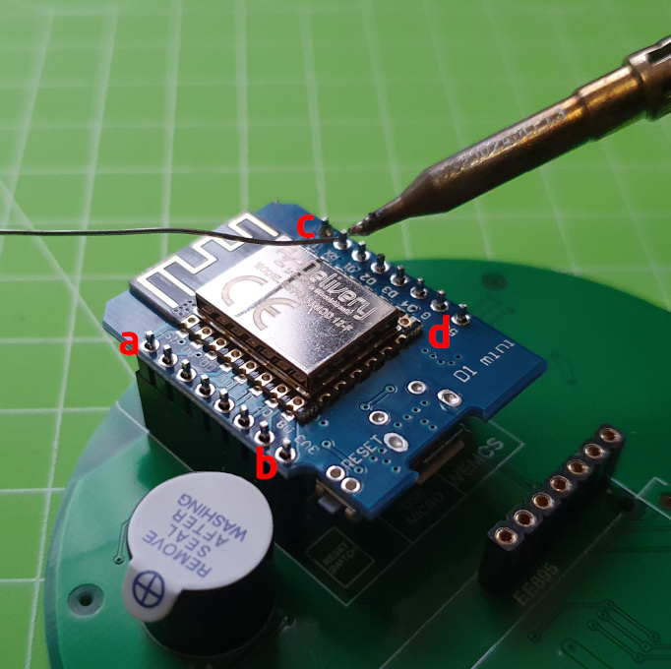
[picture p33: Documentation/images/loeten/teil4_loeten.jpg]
Teil IV - Löten


4. Jetzt könnt ihr ihn loslassen und die restlichen Pins anlöten. Auch hier wieder die Platine so drehen, dass ihr von außen die Lötspitze ansetzen könnt.
5. **Qualitätskontrolle:** Auch nach diesem Schritt bitte nochmal alle Lötstellen wie oben beschrieben prüfen.

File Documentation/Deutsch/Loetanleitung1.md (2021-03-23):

# CO2-Ampel Lötanleitung - PCB v4.1

## Teil I: Stiftleisten, Sockel und Buzzer

### Benötigte Bauteile
1. Buchse 8pin (2x): Diese findet ihr beim D1 Mikrocontroller
2. Buchse 7pin (1x)
3. Stiftleiste 6pin (1x): Diese findet ihr bei der bmp280 Platine
4. Buzzer (1x)
5. SMD bestückte Platine

### Benötigtes Werkzeug
* 3D-gedruckte Löthilfe für die Platine
* Lötstation (temperaturgeregelt)
* Lötrauchabsaugung
* Lötzinn (bleifrei 0.5-0.75mm Durchmesser)
* Seitenschneider
* Schutzbrille

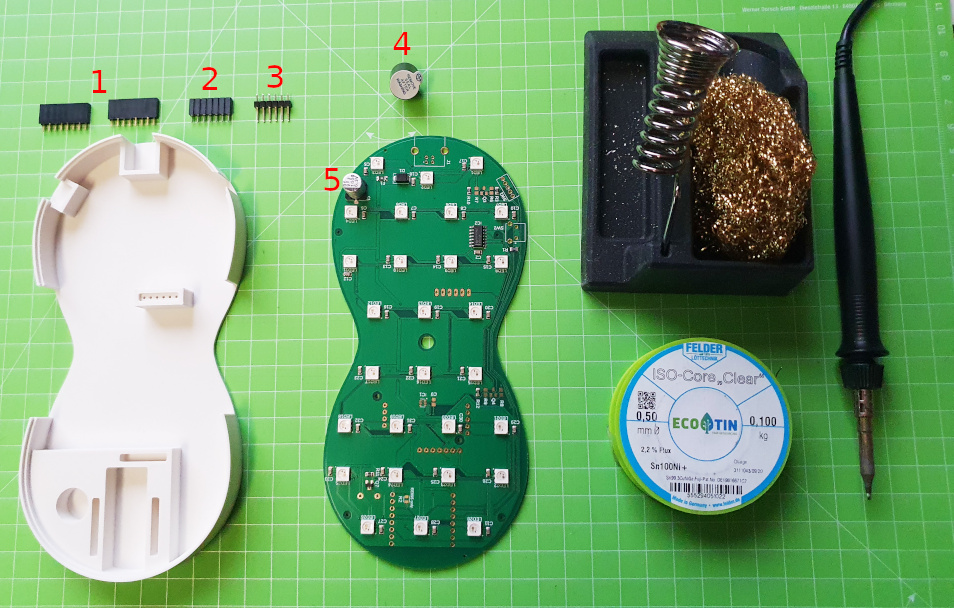
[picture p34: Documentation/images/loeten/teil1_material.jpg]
Bauteile und Werkzeug Teil I


### Arbeitsschritte
1. Kürzt mit einem Seitenschneider die langen Pins der **6Pin Stiftleiste**. Die Pins sollten auf beiden Seiten etwa gleich lang heraus stehen. Das vereinfacht eucht später das Löten. Wenn ihr keinen Seitenschneider habt, könnt ihr diesen Schritt aber auch überspringen. **VORSICHT VERLETZUNGSGEFAHR** Beim Schneiden können die abgeschnittenen Spitzen umher fliegen. Hier solltet ihr zur Sicherheit eine Schutzbrille aufziehen. 
2. Setzt die beiden 8pin Buchsen in die Löthilfe ein (a+b)
3. Setzt die 7pin Buchse in die Löthilfe ein (c)
4. Setzt die 6pin Stiftleiste in die Löthilfe ein (d). **WICHTIG:** Falls ihr in Schritt 1 die Beinchen nicht gekürzt habt, dann die kurzen Beinchen nach oben raus schauen lassen.
5. Buzzer (e) auf die Platine stecken (auf der Seite **ohne** LEDs). Falls der Buzzer beim Drehen der Platine abfällt, dann die Beinchen leicht zusammen drücken und dann nochmals einstecken. **WICHTIG:** Achtet hier auf die richtige Polarität. (+ auf dem Buzzer zu + auf der Platine).

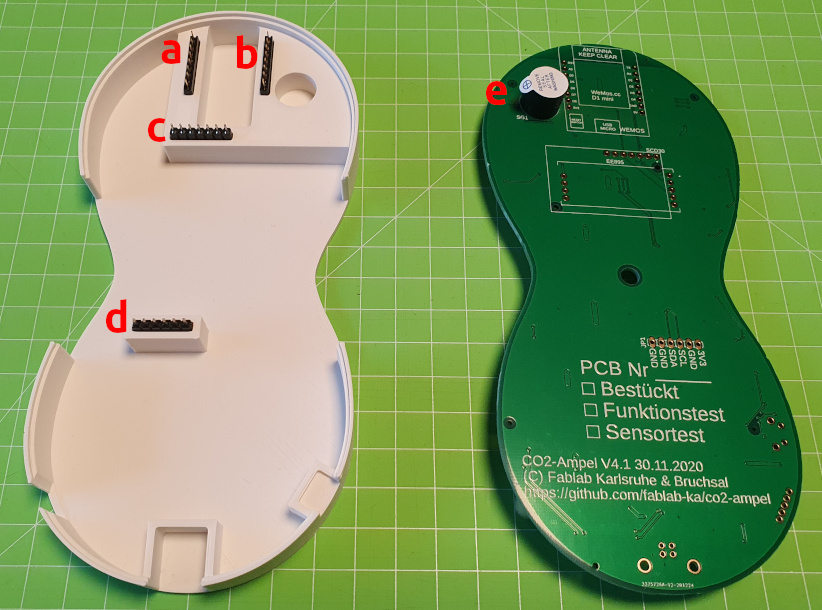
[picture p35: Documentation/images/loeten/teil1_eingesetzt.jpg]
Teil1 Bauteile eingesetzt


6. Platine vorsichtig auf die Löthilfe stecken. Evtl. etwas rütteln, so dass die Stiftleisten in die Löcher der Platine rutschen. Wenn alles passt, dann die Platine fest in die Löthilfe drücken, so dass die Ränder bündig sind. 

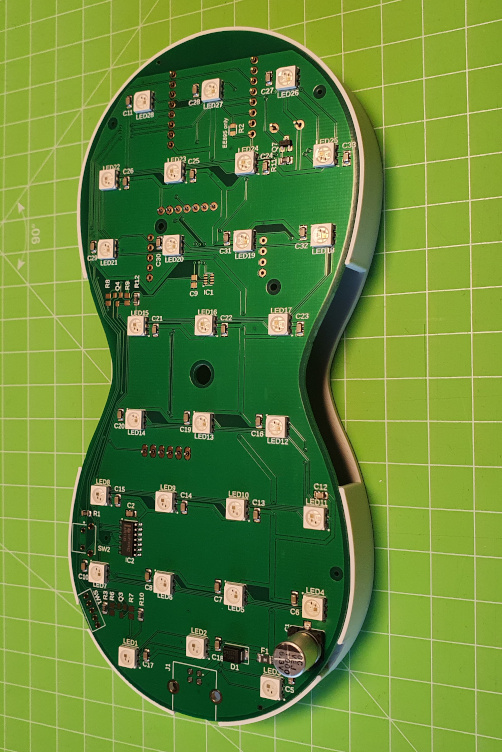
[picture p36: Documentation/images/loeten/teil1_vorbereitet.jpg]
Teil1 alles vorbereitet zum Löten


7. Jetzt könnt ihr alle Pins anlöten. Achtet darauf, dass ihr den Lötkolben nur max 2-3 Sekunden an die Lötstelle haltet. 
8. **Qualitätskontrolle:** Das ist der wichtigste Schritt und erspart euch später viel Zeit bei der Fehlersuche. Prüft nochmals alle Lötstellen und schaut nochmal, ob ihr wirklich **kein Bauteil oder Pin vergessen** habt. Die **Lötstellen** sollten **glatt und leicht konisch** sein. Wenn sie rau sind, habt ihr vermutlich eine kalte Lötstelle. Dann solltet ihr das Lötzinn nach einer kurzen Abkühlphase nochmals erhitzen. 

Prüft am Schluss noch einmal, dass **keine Lötstellen miteinander verbunden** sind. Das kann später einen Kurzschluss verursachen und im schlimmsten Fall die Bauteile zerstören.

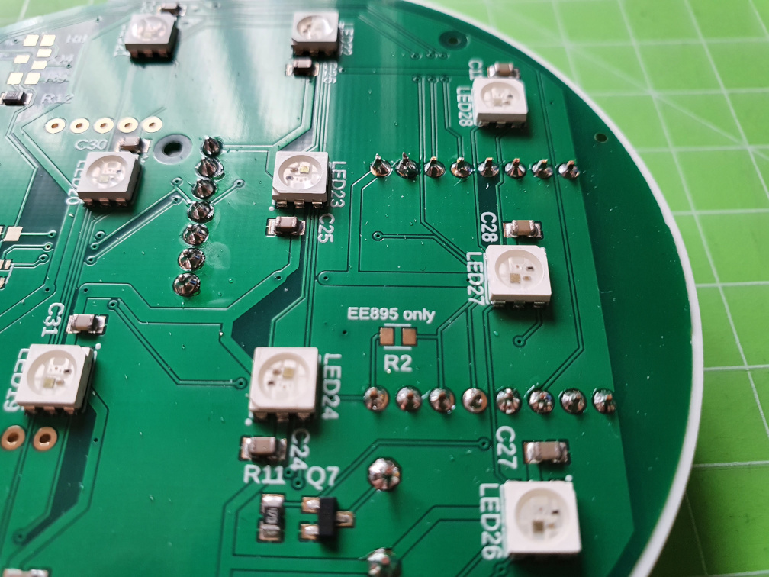
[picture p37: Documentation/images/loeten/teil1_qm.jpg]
Teil1 Qualitätskontrolle


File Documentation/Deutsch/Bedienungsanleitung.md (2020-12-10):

# Bedienungsanleitung CO2-Ampel V2

Diese Bedienungsanleitung richtet sich an diejenigen Benutzer, die eine einsatzbereite CO2 Ampel V2 in Betrieb nehmen möchten oder die Fragen zum Betrieb des Geräts haben.

## Kurzanleitung

Die CO2-Ampel lässt sich in wenigen Schritten in Betrieb nehmen. Die einzelnen Schritte werden im den folgenden Kapiteln im Detail erklärt.

1. Gerät an der Wand befestigen
   * Gut sichtbare Stelle
   * Keine direkte Sonneneinstrahlung
   * Nicht direkt am Fenster
2. Stromversorgung anschließen
   * USB-Steckernetzgerät, 5V, mindestens 1A
   * USB-Kabel mit USB Stecker Typ B
3. Zur WLAN-Anbindung (optional):
   * Mit dem WLAN-Zugangspunkt verbinden, den die Ampel in den ersten zwei Minuten nach dem Einschalten aufmacht.
   * Adresse 192.168.4.1 im Browser öffnen.
   * Mit Passwort anmelden, das zusammen mit dem Gerät übergeben  wurde.
   * Internetzugang konfigurieren und speichern.
4. Den Farbcodes folgen:
   * *Grün*: Alles OK! Falls gerade gelüftet wurde, können die Fenster wieder geschlossen werden.
   * *Gelb*: Grenzwert überschritten. Schnellstmöglich lüften!
   * *Rot*: Grenzwert deutlich überschritten. Umgehend lüften!
5. Das Gerät kann bei Nichtbenutzung von Stromnetz getrennt werden, zum Beispiel über Nacht oder über das Wochenende.

## Installation und Stromversorgung
Zur Inbetriebnahme muss die Ampel an der Wand befestigt werden und über ein USB-Kabel mit Strom versorgt werden.

### Standort
Die Ampel sollte in ca. 1,5 m bis 2,2 m Höhe so an der Wand befestigt werden, dass sie für alle im Raum befindlichen Personen gut einsehbar ist. Bitte beachten Sie, dass sich eine Steckdose für die Stromversorgung in der Nähe befindet. Um das Messergebnis nicht zu verfälschen, sollte das Gerät keiner direkten Sonneneinstrahlung ausgesetzt sein. Außerdem sollte es sich nicht in der Nähe eines geöffneten Fensters befinden.
 Sofern eine WLAN-Anbindung gewünscht ist, muss darauf geachten werden, dass ein ausreichend starkes WLAN-Signal verfügbar ist.
Die Ampel ist ausschließlich für die Verwendung in trockenen Räumen konzipiert.

### Stromversorgung
Für die Stromversorgung der Ampel benögigen Sie ein USB-Steckernetzgerät und eine Kabel mit ausreichender Länge:

* USB Kabel Stecker Typ A auf Stecker Typ B
* USB Steckernetzgerät mit Buchse Typ A, 5V, mindestens 1A

### Montage
Zum Aufhängen der Ampel können Sie wahlweise und je nach Beschaffenheit der Wand einen Nagel (ca. 4 cm Länge), eine Schraube mit Dübel (S4 oder S5) verwenden. Falls nicht gebohrt oder genagelt werden kann, kann die optionale Wandhalterung mit Klebepads an der Wand fixiert werden und die Amplel darin eingeklickt werden. Das USB-Kabel kann bei Bedarf zusätzlich mit Kabelklemmen an der Wand befestigt werden.

### Einschalten
Die Ampel schalten sich automatisch ein, sobald sie mit der Stromversorgung verbunden wird. Zunächst sollten beide Ampelfelder kurz weiß aufleuchten, danach wird entsprechend dem CO2-Gehalt der Luft eine Farbe angezeigt. Ein Blinken der Ampel deutet auf einen Fehler hin. Siehe Abschnitt Fehlerbehebung unten.

### Konfiguration der WLAN-Verbindung (optional)

> 	Hinweis: Bitte beachten Sie die Hinweise zum Datenschutz unten, bevor Sie mit der Konfiguration der WLAN-Verbindung fortfahren!

Direkt nach dem Einschalten der Ampel versucht diese zunächst, sich mit einem bereits zuvor konfigurierten WLAN-Zugangspunkt zu verbinden. Gelingt dies nicht innerhalb dreißig Sekunden, oder war zuvor kein Zugangspunkt konfiguriert worden, so macht die Ampel einen für 2 Minuten eigenen Zugangspunkt auf, über den der WLAN-Zugriff im Anschluss konfiguriert werden kann. Gehen Sie folgendermaßen vor, um die WLAN-Verbindung zu konfigurieren:

1. Verbinden Sie die Ampel mit der Stromversorgung.
2. Öffnen Sie an Ihrem PC oder auf Ihrem Smartphone die WLAN-Konfiguration und warten Sie ab, bis ein Zugangspunkt *CO2Ampel-XXXXXXXX* in der Liste der verfügbaren Zugangspunkte erscheint.
3. Verbinden Sie Ihren PC bzw. Ihr Smartphone mit diesem Zugangspunkt um sich direkt mit der Ampel zu verbinden.
4. Geben Sie die IP-Adresse *192.168.4.1* in die Adresszeile Ihres Browsers ein und laden Sie die Seite.
5. Melden Sie sich mit dem Passwort an, das Sie zusammen mit der CO2-Ampel erhalten haben.
6. Tragen Sie nun die Details des Zugangspunkts ein, mit dem die Ampel verbunden werden soll. Es handelt sich um die selben Daten, die Sie auch auf Ihrem PC oder Smartphone eintragen würden, um sich mit dem Internet zu verbinden.
7. Speichern Sie die Eintragungen und warten Sie die Bestätigung ab.

Bei einer bestehenden WLAN-Verbindung wird empfohlen, die Ampel dauerhaft am gleichen Ort zu betreiben, da die protokollierten Messwerte ansonsten wenig aussagekräftig sein werden.

## Optische und akustische Signale

Die CO2-Ampel misst laufend den CO2-Gehalt der Raumluft und zeigt durch optische und akustisches Signale an, falls der Messwert [den vom Bundesumweltamt empfohlenen Grenzwert](https://www.umweltbundesamt.de/sites/default/files/medien/2546/dokumente/irk_stellungnahme_lueften_sars-cov-2_0.pdf) überschreitet. Da der CO2-Gehalt der Raumluft ein Indikator für eine mögliche Virenbelastung der Raumluft darstellt, deutet er auf ein erhöhtes Ansteckungsrisiko mit durch über Aerosole übertragene Infektionskrankheiten hin. Das tatsächliche Ansteckungsrisiko hängt jedoch von einer Vielzahl von Faktoren ab. Die Verwendung der CO2-Ampel kann helfen, das Ansteckungsrisiko zu reduzieren, sie garantiert jedoch keinerlei Schutz vor einer Ansteckung!

### Optische Signale
Die folgende Tabelle gibt die Bedeutung der Farben und die empfohlenen Handlungen an. 

|Farbcode|Bedeutung|Empfohlene Aktion|
|---|---|---|
|GRÜN<p>(unteres&nbsp;Feld)|CO2-Grenzwert unterschritten.|Fenster können geschlossen werden, sofern gerade gelüftet wurde.|
|GELB<p>(oberes&nbsp;Feld)|CO2-Grenzwert **überschritten**.|Es sollte **schnellstmöglich** gelüftet werden!|
|ROT<p>(oberes&nbsp;Feld)|CO2-Grenzwert **deutich überschritten**.|Es muss **umgehend** gelüftet werden!|

Zum effizienten Lüften des Raumes würd eine **Sturmlüftung** empfohlen. Das heißt, es sollten möglichst alle Fenster komplett geöffnet werden. Die Ampel ist so konzipiert, dass sie beim Lüften erst dann auf grün umschaltet, wenn der CO2-Grenzwert **deutlich unterschritten** wird. Die Fenster können also gleich im Anschluss geschlossen werden.

### Akustische Signale
Bei ansteigendem CO2-Wert ertönt bei jedem Wechsel der Farben ein **akustisches Signal**. Beim fallendem CO2-Wert ertönt beim Wechsel auf grün ebenfalls ein Signal, das angibt, dass die Fenster nun geschlossen werden können.

## Datenschutz

Nach erfolgreicher WLAN-Konfiguration wird die Ampel in regelmäßigen Abständen Messdaten an einen Server im Internet übertragen. Diese umfassen den CO2-Gehalt der Raumluft, die Temperatur und die Luftfeuchtigkeit. Die Daten erlauben Rückschlüsse auf die Anzahl der im Raum befindlichen Personen, auf die Häufigkeit des Lüftens und insbesondere auf die Einhaltung der Empfehlungen zum regelmäßigen Lüften.

Der Server zur Protokollierung der Messwerte ist in der Software des Geräts hinterlegt. Wenn Sie die Ampel vom FabLab Karlsruhe e.V. erhalten haben, bedeutet dies:

* Die Daten werden auf den Server co2-ampel.fablab-karlsruhe.de übertragen. Es handelt sich dabei um einen virtuellen Server, den wir in Deutschland bei der Fa. Hetzner hosten. Betreiber ist der Verein FabLab Karlsruhe e.V.
* Um Zugriff auf die Daten bzw. das Dashboard zu erhalten, schreiben Sie uns bitte eine E-Mail an kontakt@coronahilfe-karlsruhe.de 
* Auf die Werte ihrer Ampeln haben nur von Ihnen genannte Personen Zugriff. Zusätzlich haben noch unsere Systemadministratoren Zugriff.
* Die Daten werden zur Darstellung in dem von uns bereitgestellten Dashboard verarbeitet. Weiterhin werden sie in anonymisierter Form zur bedarfsgerechten Gestaltung, der Weiterentwicklung und der Optimierung des Dashboards durch unsere Systemadministratoren genutzt. Eine Weitergabe an Dritte erfolgt nicht.

## Fehlerbehebung
Falls die Ampel nicht leuchtet oder ein blinkender Farbcode angezeigt wird, liegt womöglich ein Fehler vor. Die folgende Tabelle beschreibt einige typische Fehlerursachen.

|Symptom|Ursache|Behebung|
|---|---|---|
|Ampel leuchtet nicht|Kein Strom| Sitzen die Stecker fest? Hat die Steckdose Strom? Funktioniert die Ampel mit einem anderen Kabel bzw. einem anderen Steckernetzgerät?|
|Ampel leuchtet nicht|LEDs sind ausgeschaltet| Der kleine Schiebeschalter seitlich unten and er Ampel muss nach oben zeigen, damit die Ampel leuchtet. Bitte überprüfen Sie die Position des Schalters!|
|Ampel blinkt *gelb*|CO2-Wert zu niedrig|Der gemessene CO2-Wert ist unrealistisch niedrig. Gerät muss überprüft werden.|
|Ampel blinkt abwechselnd *gelb* und *rot*|CO2-Sensor nicht erkannt|Ein Problem mit dem CO2-Sensor ist aufgetreten. Gerät muss überprüft werden.|
|Ampel blinkt *blau*|Gemessener Luftdruck zu gering|Der gemessene Luftdruck istt unrealistisch gering. Gerät für 10 Sekunden von Stromversorgung trennen. Bei wiederholtem Auftreten Gerät überprüfen.|
|Ampel blinkt abwechselnd *blau* und *rot*|Luftdrucksensor nicht erkannt|Ein Problem mit dem Luftdrucksensor (BMP280) ist aufgetreten. Gerät muss überprüft werden.|

## Technische Daten
In diesem Kapitel werden die wichtigsten technischen Daten der CO2-Ampel V2 zusammengefasst.

### Stromversorgung

|Merkmal|Wert|
|---|---|
|Betriebsspannung|5 V Gleichspannung|
|Stromaufnahme|ca. 500 mA|
|Leistungsaufnahme|ca. 2,5 W|

### CO2-Grenzwerte
Steigender CO2-Wert (Fenster geschlossen):

|CO2-Gehalt|Farbe|
|---|---|
|<=&nbsp;1000&nbsp;ppm|GRÜN|
|>&nbsp;1000&nbsp;ppm<p><=&nbsp;2000&nbsp;ppm|GELB|
|>&nbsp;2000&nbsp;ppm|ROT|

Fallender CO2-Wert (während des Lüftens):

|CO2-Gehalt|Farbe|
|---|---|
|<=&nbsp;800&nbsp;ppm|GRÜN|
|>&nbsp;800&nbsp;ppm<p><=&nbsp;1500&nbsp;ppm|GELB|
|>&nbsp;1500&nbsp;ppm|ROT|

## Entsorgung

Wie alle elektronischen Geräte darf die CO2-Ampel nicht im Hausmüll entsorgt werden. Wir empfehlen, defekte oder nicht mehr benötigte Geräte an den Hersteller zurückzugeben.

Zur Entsorgung kann das Gehäuse der Ampel zerlegt werden, indem die Schraube an der Rückseite entfernt und der Deckel abgezogen wird. Das Gehäuse und die Schreiben können dann im Hausmüll entsorgt werden. Die Platine, das Netzgerät und das Kabel müssen bei einer Sammelstelle für Elektroschrott abgegeben werden.

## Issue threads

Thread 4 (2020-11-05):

NCP1117ST25T3G statt NCP1117ST33T3G

ARKopp, 2020-11-05:
Wir haben gerade noch bemerkt dass ihr eine falsche Bauteilbezeichnung drin habt in der shematic ...

ARKopp, 2020-11-05:
hier habt ja den 2,5 und nicht den 3,3 verbaut

towaho, 2020-11-05:
Meinst du in https://github.com/fablab-ka/co2-ampel/blob/master/PCB/Sensoren.pdf ?

ARKopp, 2020-11-05:
ja genau.

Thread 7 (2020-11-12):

Schaltpläne in "modifzierbar"?

smurfix, 2020-11-12:
Hallo Leute,
wie wäre es, den Schaltplan online zu stellen statt nur die PDFs und den Gerber-Output?
So ist das nicht wirklich hackerfreundlich …

Eagle oder (noch besser) Kicad wäre superb.

towaho, 2020-11-12:
Wir haben die Platine in Fusion360 und somit Eagle erstellt. Die Fusion Projektdatei findest du hier: https://github.com/fablab-ka/co2-ampel/blob/master/Case/Fusion360/CO2-Ampel.f3z

smurfix, 2020-11-12:
Ah. Danke, die hatte ich total übersehen.

Kicad kann Eagle importieren, aber nur die älteren .brd/.sch-Formate. Wenn ihr die generieren könnt, kann ich mal testen ob man mit dem Resultat was anfangen kann.

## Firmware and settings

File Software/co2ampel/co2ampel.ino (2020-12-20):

/*
  CO2 Ampel - PCB v2.0 + v1.0
  By: FabLab Karlsruhe e.V., Nils Roßmann
  https://github.com/fablab-ka/co2-ampel/
  Date: 14.11.2020
  License: MIT
*/

/* TODO
 *  adjust temperature offset due to new case
 *  check humidity and warn if lower than 40%
 *  create a class for mqtt, wifi etc.
 *  ntp+ssl cert check?
 */

#include <Wire.h>
#include "SparkFun_SCD30_Arduino_Library.h" // https://github.com/sparkfun/SparkFun_SCD30_Arduino_Library (1.0.8)
#include <Adafruit_BMP280.h> // https://github.com/adafruit/Adafruit_BMP280_Library (2.1.0)
#include <Adafruit_BME280.h> //https://github.com/adafruit/Adafruit_BME280_Library
#if defined(ESP8266)
#include <ESP8266WiFi.h>
#elif defined(ESP32)
#include <WiFi.h>
#endif

#include "ConfigManager.h"
#include "config.h"
#include "mqtt.h"
#include "wifi.h"
#include "buzzer.h"
#include "led.h"
#include "bmx.h"
#include "co2ampel.h"

SCD30 airSensor;

uint16_t green_th;
uint16_t yellow_thL;
uint16_t yellow_thH;
uint16_t red_th;

Color currentCO2Color=GREEN;

uint32_t mqttLastSend = 0;
uint32_t mqttLastTry = 0;
uint32_t scd30LastUpdate = 0;
uint8_t recalibrateSwitch=0;
uint32_t lastSwitchChange=0;

bool scd30Ready=false;

// ConfigManager
ConfigManager configManager;
uint8_t configStatus;


/* functions */

void selftest() 
{
  ledSetColor(WHITE);
  delay(5000);
  bool ok=true;
  sensors_event_t pressureEvent;
  uint16_t co2=0;
  uint16_t bmxEnabled = configManager.getUintValue("bmx_enabled", BMX_ENABLED);
  
  if((!isBmxReady()&&bmxEnabled) || !scd30Ready) ok=false;
  else {
    uint8_t i=0;
    while (co2<SCD30_MIN_PPM && i++<10) { 
      while (!digitalRead(GPIO_SCD30_RDY) || ! airSensor.dataAvailable()) {
        delay(500);
      }
      co2 = airSensor.getCO2();
    }
    if (co2 < SCD30_MIN_PPM) {
      Serial.print("co2 too low: ");
      ok=false;
    } else Serial.print("co2 ok: ");
    Serial.println(co2);

    if(isBmxReady()) {
    bmxPressure->getEvent(&pressureEvent);  
      if (pressureEvent.pressure < 700) {
        Serial.print("pressure too low ");
        Serial.println(pressureEvent.pressure);
        ok=false;
      }
    }
  }
  uint16_t beepEnabled = configManager.getUintValue("selftest_buzzer", SELFTEST_BUZZER);
  
  if(ok) {
    if(beepEnabled) beepOK(configManager);
    ledBlink(GREEN,DARK,2500);
  }
  else {
    if(beepEnabled) beepFailure(configManager);
    
    if( bmxEnabled && !isBmxReady() ) ledBlink(BLUE,RED,5000);
    else if(pressureEvent.pressure < 700) ledBlink(BLUE,DARK,5000);
    else if (co2 < SCD30_MIN_PPM) ledBlink(YELLOW,DARK,5000);
  }
}

void scd30ForceRecalibration(uint16_t concentration) {
  bool ok = airSensor.setForcedRecalibrationFactor(concentration);
  Serial.print("calibration status: ");
  Serial.println(ok);
  if (ok) ledBlink(GREEN,DARK,2000);
  else ledBlink(RED,DARK,2000);
}

void setConfig(String& jsonString) {
  uint8_t err = configManager.writeConfig(jsonString,"/config.json");
  if(err!=0) {
    Serial.println("failed writing new config.json");
  } else {
    Serial.println("saved new config.json to flash");
  }
  while (1) // freez and reboot due to watchdog
  ;
}

void startCalibration() {

  uint16_t calibration_ppm = configManager.getUintValue("calibration_ppm", SCD30_CALIBRATION_PPM);
  
  ledSetColor(YELLOW2);
  delay(600000); // wait 10min
  bool ok = false;
  uint8_t calCount=0;
  while (!ok && calCount<5) {
    ok = airSensor.setForcedRecalibrationFactor(calibration_ppm);
    Serial.print("calibration status from sensor: ");
    Serial.println(ok);
    ledSetColor(BLUE);
    uint8_t okcount=0;
    uint16_t co2=0;
    uint16_t co2last=0;
    while (okcount<10) {  
      while (!digitalRead(GPIO_SCD30_RDY) || ! airSensor.dataAvailable()) {
        delay(500);
      }
      co2 = airSensor.getCO2();
      uint16_t delta=abs(co2last-co2);
      Serial.print("co2: ");
      Serial.print(co2);
      Serial.print(" delta: ");
      Serial.println(delta);
      if(delta<=10) okcount++;
      else okcount=0;
      co2last=co2;
    }
    ledSetColor(YELLOW2);
    delay(60000);
    
    // check the next 20 values whether they are within the specification: +-(30ppm+3%MV)
    uint16_t co2min=calibration_ppm-(30+0.03*calibration_ppm);
    uint16_t co2max=calibration_ppm+(30+0.03*calibration_ppm);
    for (uint8_t i=0; i < 20; i++) {
      while (!digitalRead(GPIO_SCD30_RDY) || ! airSensor.dataAvailable()) {
        delay(500);
      }
      co2 = airSensor.getCO2();
      if(co2<co2min || co2>co2max) {
        Serial.print("measured value outside specification: ");
        Serial.println(co2);
        ok=false;
        break;
      } else {
        Serial.print("measured value ok: ");
        Serial.println(co2);
      }
    }
  }
  if (ok) {
    ledBlink(GREEN,DARK,2000);
    ledSetColor(GREEN2);
  }
  else {
    ledBlink(RED2,DARK,2000);
    ledSetColor(RED);
  }
  while(1) {
    delay(1000);
  }
}


/**************************** setup() *************************************************/

void setup()
{
  Serial.begin(115200);
  setupLED();

  // init IOs
  #ifdef GPIO_SWITCH
  pinMode(GPIO_SWITCH, INPUT);
  #endif

  
  pinMode(GPIO_BUZZER, OUTPUT);
  digitalWrite(GPIO_BUZZER,0);

  delay(500);
  Serial.print("Start CO2-Ampel Version: ");
  Serial.println(VERSION);

  configStatus=configManager.readConfig("/config.json");
  ledSetBrightnes(configManager.getUintValue("led_brightness", LED_BRIGHTNES));

  // check if mqtt credentials are set
  if(configStatus==0) {
    if(configManager.getCharValue("mqtt_password", "")=="" || configManager.getCharValue("mqtt_username", "")=="") {
      configStatus=1;
      Serial.println("mqtt username and password not set in config.json");
    }
  }
  
  if(configStatus!=0) {
    Serial.println("could not read config.json, try reading backup.json");
    configStatus=configManager.readConfig("/backup.json");
    if(configStatus==0) {
      uint8_t err = configManager.writeConfig("/config.json");
      if(err) {
        Serial.println("could not restore config.json");
      } else {
        Serial.println("restored config.json with backup.json");
      }
    }
  }

  green_th = configManager.getUintValue("th_green", TH_GREEN);
  Serial.print("green_th: ");
  Serial.println(green_th);
  yellow_thL = configManager.getUintValue("th_yellow_low", TH_YELLOW_LOW);
  yellow_thH = configManager.getUintValue("th_yellow_high", TH_YELLOW_HIGH);
  red_th = configManager.getUintValue("th_red", TH_RED);
    
  if(configStatus==0 && configManager.getUintValue("wifi_enabled", WIFI_ENABLED)) {
      setupWifi(configManager);
      setupMQTT(configManager);
  }

  Wire.begin();

  // Init SCD30
  if (airSensor.begin(Wire, SCD30_AUTOCALIBRATION) == false)
  {
    Serial.println("Air sensor not detected. Please check wiring. Freezing...");
    ledBlink(YELLOW,RED,5000);
    while (1) // freez and reboot due to watchdog
      ;
  } else {
    scd30Ready=true;
  }
  airSensor.setAmbientPressure(1005);
  airSensor.setMeasurementInterval(SCD30_MEASUREMENT_INTERVAL);
  airSensor.setTemperatureOffset(SCD30_TEMP_OFFSET);

  // Init bmp280
  if (configManager.getUintValue("bmx_enabled", BMX_ENABLED)) {
    bmxSetup();
  }
  if(configManager.getUintValue("selftest_enabled", SELFTEST_ENABLED)) selftest();
}

/**************************** loop() *************************************************/

void loop()
{
  if(configStatus==0 && configManager.getUintValue("wifi_enabled", WIFI_ENABLED)) {
    loopWifi(configManager);
    loopMQTT(configManager);
  }

#ifdef GPIO_SWITCH
  // check recalibration switch
  if(millis() < 60000 && abs(millis()-lastSwitchChange) > 500) {
    int switchState = digitalRead(GPIO_SWITCH);
    if(switchState==1 && recalibrateSwitch==0) {
      recalibrateSwitch++;
      lastSwitchChange=millis();
      Serial.println("switch is on at start");
    }
    if(switchState==0 && recalibrateSwitch==1) {
      recalibrateSwitch++;
      lastSwitchChange=millis();
      Serial.println("switch is off");
    }
    if(switchState==1 && recalibrateSwitch==2) {
      recalibrateSwitch++;
      lastSwitchChange=millis();
      Serial.println("switch is on again");
    }
  }
  if(recalibrateSwitch>=3) {
    Serial.println("start Calibration");
    recalibrateSwitch=0;
    startCalibration();
  } 
#endif

  int co2Available=digitalRead(GPIO_SCD30_RDY);

  if(abs(millis()-scd30LastUpdate) > SCD30_MEASUREMENT_INTERVAL*50000) {
    Serial.println("didn't received co2 updates for some time");
    airSensor.sendCommand(0xD304);
    delay(1000);
    while (1) // freez and reboot due to watchdog
   ;  
  }
  
  if (co2Available && airSensor.dataAvailable())
  {
    scd30LastUpdate=millis();
    uint16_t co2 = airSensor.getCO2();
    Serial.print(co2);   
    Serial.print(" ");
    double hum = airSensor.getHumidity();
    Serial.print(hum);
    Serial.print(" ");
    double temp = airSensor.getTemperature();
    Serial.print(temp);
    Serial.print(" ");

    sensors_event_t temp_event, pressure_event;
    double pressure = 0.0;
    double temp2 = 0.0;
    if (isBmxReady()) {  
      bmxTemp->getEvent(&temp_event);
      bmxPressure->getEvent(&pressure_event);
      temp2 = temp_event.temperature;  
      Serial.print(temp2);
      Serial.print(" ");
      pressure = pressure_event.pressure;
      Serial.print(pressure);
      Serial.print(" ");
    }
    
    Color co2Color=GREEN;
    if ( currentCO2Color == GREEN && co2 >= yellow_thL || currentCO2Color == YELLOW && co2 > green_th || currentCO2Color == RED && co2 <= yellow_thH ) {
      co2Color=YELLOW;
      Serial.print("yellow ");
    }
    if ( co2 >= red_th || currentCO2Color == RED && co2 > yellow_thH) {
      co2Color=RED;
      Serial.print("red ");
    }
    float RssI = WiFi.RSSI();
    Serial.print(RssI);
    Serial.println();
        
    //if(color != currentCO2Color) 
    ledSetColor(co2Color);
    if (co2Color==GREEN && currentCO2Color != co2Color) {
      beep(configManager,1);
    //  airSensor.setTemperatureOffset(SCD30_TEMP_OFFSET);
    }
    if (co2Color==YELLOW && currentCO2Color==GREEN) {
      beep(configManager,2);
     // airSensor.setTemperatureOffset(SCD30_TEMP_OFFSET+3);
    }
    if (co2Color==RED && currentCO2Color != co2Color) {
      beep(configManager,3);
     // airSensor.setTemperatureOffset(SCD30_TEMP_OFFSET+1.5);
    }
    currentCO2Color=co2Color;

    if (configStatus==0 && configManager.getUintValue("wifi_enabled", WIFI_ENABLED)) {
      if ( abs(millis() - mqttLastSend) >= configManager.getUintValue("mqtt_interval", MQTT_INTERVAL)) {
        mqttLastSend=millis();
        publishValues(configManager,co2, hum, temp, pressure,temp2,co2Color,RssI, millis()
        );
      }
    }

    if (isBmxReady()) {
      Serial.print("set pressure: ");
      Serial.println(pressure);
      airSensor.setAmbientPressure(pressure);
    }
  }
}

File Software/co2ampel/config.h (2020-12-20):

/*
  CO2 Ampel - PCB v2.0 + v1.0
  By: FabLab Karlsruhe e.V., Nils Roßmann
  https://github.com/fablab-ka/co2-ampel/
  Date: 13.10.2020
  License: MIT
*/

#ifndef CONFIG_H
#define CONFIG_H

/******************************* Version **************************************/
#define VERSION 7

/******************************* MQTT **************************************/

#define MQTT_HOST "co2-mqtt.fablab-karlsruhe.de" // overriden by mqtt_host from config.json 
#define MQTT_PORT 443 // overriden by mqtt_port from config.json 

#define SSL_FINGERPRINT "06 d8 e3 d2 f7 5c 57 69 45 29 f6 4e 8c 3e 19 95 32 39 b4 6e" // overriden by ssl_fingerprint from config.json 
#define MQTT_INTERVAL 4000 // overriden by mqtt_interval from config.json 


/******************************* WIFI **********************SCD30_MEASUREMENT_INTERVAL****************/

#define WIFI_ENABLED 1 // overriden by wifi_enabled from config.json 
#define WIFI_AP_SSID "CO2Ampel" // overriden by wifi_ap_ssid from config.json 
#define WIFI_AP_PASSWORD "CHANGEME" // overriden by wifi_ap_password from config.json 
#define WIFI_PORTAL_TIMEOUT 120 //seconds // overriden by wifi_portal_timeout from config.json 
#define WIFI_CONNECT_TIMEOUT 60 //seconds // overriden by wifi_connect_timeout from config.json 

/******************************* Colors **************************************/
enum Color {GREEN, YELLOW, RED, BLUE, DARK, WHITE, GREEN2, YELLOW2, RED2};


/******************************* scd30 **************************************/
#define SCD30_AUTOCALIBRATION 0
#define SCD30_CALIBRATION_MIN_RUNTIME 180 //seconds
#define SCD30_MEASUREMENT_INTERVAL 2 // seconds (recalibrate, if you change this value)
#define SCD30_MIN_PPM 350
#define SCD30_CALIBRATION_PPM 450 // overriden by calibration_ppm from config.json 

/******************************* thresholds **************************************/
#define TH_GREEN 800 //overriden by th_green from config.json
#define TH_YELLOW_LOW 1000 //overriden by th_yellow_low from config.json
#define TH_YELLOW_HIGH 1500 //overriden by th_yellow_high from config.json
#define TH_RED 2000 //overriden by th_red from config.json

/******************************* MISC **************************************/
#define CONFIGMANAGER_DEBUG 1

/* ***************************** PCB Revision *************************/
#define PCBV2



/************************* ESP8266 PCB V2*********************************/
/* esp8266 D1 mini PINOUT
 *  A0 ununsed
 *  D0 GPIO16 Switch 
 *  D1 GPIO5  I2C SCL
 *  D2 GPIO4  I2C SDA
 *  D3 GPIO0  LED_DATA 2 (sad face)
 *  D4 GPIO2 unused
 *  D5 GPIO14 Buzzer
 *  D6 GPIO12 LED_DATA 1 (happy face)
 *  D7 GPIO13 SCD30 Ready
 *  D8 GPIO15 unused
 *  TX GPIO1 unused
 *  RX GPIO3 unused
 */

#ifdef PCBV2
// LEDS
#define NUMPIXELS1 14
#define NUMPIXELS2 14
#define GPIO_LED1 12
#define GPIO_LED2 0
#define LED_BRIGHTNES 128 // % (0=dark, 255=full) overriden by led_brightness from config.json
//SCD30
#define GPIO_SCD30_RDY 13
#define SCD30_TEMP_OFFSET 7.0
// Switch
#define GPIO_SWITCH 16
// BUZZER
#define GPIO_BUZZER 14
#define BUZZER_ENABLED 1 //overriden by buzzer_enabled from config.json
// BM(E/P)280
#define BMX_ENABLED 1 //overriden by bmx_enabled from config.json
// self test
#define SELFTEST_ENABLED 1 //overriden by selftest_enabled from config.json 
#define SELFTEST_BUZZER 0 //overriden by selftest_buzzer from config.json 

#endif



/************************* ESP8266 PCB V1*********************************/
/* esp8266 D1 mini PINOUT
 *  A0 unused
 *  D0 GPIO16  
 *  D1 GPIO5  I2C SCL
 *  D2 GPIO4  I2C SDA
 *  D3 GPIO0  
 *  D4 GPIO2  BUZZER
 *  D5 GPIO14 LED RED
 *  D6 GPIO12 LED YELLOW
 *  D7 GPIO13 LED GREEN
 *  D8 GPIO15 SCD30 Ready
 *  TX GPIO1  unused
 *  RX GPIO3  unused
 */
#ifdef PCBV1
// LEDS
#define GPIO_GREEN 13
#define GPIO_YELLOW 12
#define GPIO_RED 14
#define LED_BRIGHTNES 255
//SCD30
#define GPIO_SCD30_RDY 15
#define SCD30_TEMP_OFFSET 3.0
// BUZZER
#define GPIO_BUZZER 2
#define BUZZER_ENABLED 1 //overriden by buzzer_enabled from config.json
// BME280
#define BMX_ENABLED 0 //overriden by bmx_enabled from config.json
// self test
#define SELFTEST_ENABLED 1 //overriden by selftest_enabled from config.json
#define SELFTEST_BUZZER 1 //overriden by selftest_buzzer from config.json 
#endif

#endif

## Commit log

2020-08-29 added bom+gerber
    [bom_digikey.csv]
2020-09-01 corrected typo
    [bom_digikey.csv]
2020-09-24 Prototyp 2
    [Board.brd, Case.stl, Diffusor (3x).stl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]
2020-10-15 Updated version
    Prototyp 2
    [Board.brd, Schaltplan.sch]
2020-10-25 added openscad case
    [Case.stl, Diffusor (3x).stl, Lid.stl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]
2020-10-27 added BOM PCBv2
    [bom_digikey_pcb_v1.csv]
2020-10-27 renanmed BOM
2020-10-27 added tools, bom link
2020-10-27 added links, moved BOM
    [bom_digikey_pcb_v1.csv]
2020-10-27 was designed for pcb v1
    [Diffusor (3x).stl]
2020-10-27 removed v1 files
    [bom_digikey_pcb_v1.csv]
2020-10-29 BOM/CPL für jlcpcb
    Bestückungsliste und Pick+Place-Liste für jlcpcb.com hinzugefügt
    [BOM co2-ampel prototyp2 jlcpcb.xlsx, BOM co2-ampel prototyp2 seeedstudio.xlsx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]
2020-11-01 improved outline
    [case.scad, case.stl, pcb_v2.dxf]
2020-11-04 added second show, due to problems with leds turned on during setup phase
    [led.cpp]
2020-11-08 new features: backup.json, send config.json via mqtt, start calibration via mqtt, reset co2 sensor (untested)
    [ConfigManager.cpp, co2ampel.ino, config.h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]
2020-11-08 fixed wrong constant name
    [config.h]
2020-11-08 default PCBV2
2020-11-08 added resetwifi, option to disable selftest, 1x white blink: wifi connected
    [co2ampel.ino, config.h, mqtt.cpp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]
2020-11-08 added fusion v3 case
    [Case.stl, Lid.stl, glass_bottom.stl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]
2020-11-09 added calibration feature via switch
2020-11-10 updated ArduinoJson version
2020-11-11 Update ArduinoJson version in platformio as well
2020-11-13 Update README.md
    removed wrong switch
2020-11-14 Update README.md
    added correct switch
2020-11-15 replaced adafruit neopixel lib with fastled lib
    [buzzer.cpp, co2ampel.ino, config.h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]
2020-11-16 added tool for scd30 soldering
    [scd30-bestuecken.stl]
2020-11-16 fixed for pcbv1
2020-11-27 fixed led colors
2020-11-27 don't print error message if bmp280 ist disabled in config file
    [co2ampel.ino]
2020-11-28 improved calibration
2020-12-01 changed calibration ppm due to https://www.icos-cp.eu/data-products/ATM_NRT_CO2_CH4
2020-12-10 set calibration ppm via config file
2020-12-10 switch disabled only the buzzer if wifi is not connected
    [config.h, led.cpp, wifi.cpp]
2020-12-25 Updated all files for PCBv4.1
    [BOM co2-ampel prototyp2 jlcpcb.xlsx, Case.stl, Lid.stl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]
2021-03-19 added soldering documentation
2021-03-23 added links to soldering documentation
2021-03-23 added short circuit tests
